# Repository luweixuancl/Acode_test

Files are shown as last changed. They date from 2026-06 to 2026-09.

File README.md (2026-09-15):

# ESP32-C3 GNSS NTP Server

基于 **合宙 CORE ESP32-C3** + **大夏龙雀 DX-GP22** 的一级（Stratum-1）NTP 时间服务器。

## 功能

1. **OLED 状态页**：大字体本地时间；显示当前 WiFi SSID / IP；顶栏角标为星数·时钟态 / RSSI·AP；SYNC/WAIT
2. **OLED 防烧屏**：无操作（默认 10 分钟）自动关断面板，旋钮任意动作唤醒（首个动作仅唤醒不导航）；息屏时长可在 **Screen Off** 菜单或网页 `/cfg` 调档（常亮/1/5/10/30 分钟，NVS `ooff`）
3. **板载双状态 LED**（合宙 CORE 表4-1）：D4（IO12）显示运行/WiFi，D5（IO13）显示 GPS/PPS，高电平有效
4. **旋转编码器菜单**：扫描 WiFi、网页配网、静态 IP、DHCP、时区、异常策略、NTP ACL、温度补偿、息屏、NTP 统计、重启
5. **手动静态 IP**：编码器逐字节编辑；保存时通过 **ARP 探测**检测局域网是否已有相同 IP；当前 IP 与目标一致时提示 `IP unchanged` 并保持在线（不断网重连）
6. **编码器配网**：扫描附近 WiFi → 选择 SSID → 编码器输入密码 → 连接
7. **网页配网**：开启 SoftAP（`NTP-Setup-XXXX` / 密码默认 **`NTP-`+MAC 后 4 位十六进制**，与串口打印的 MAC 对应；**仅 2.4 GHz**）。`/` 始终是只读状态页。打开 `/setup` 或 `/login` 先登录，通过后才进入 `/cfg` 设置；设置页不再出现写口令输入框。`/status` `/metrics` 只读开放。若手机仍显示旧设置页，请强制刷新（缓存了刷固件前的 `/`）。
8. **网页状态**：访问 `http://<设备IP>/` 查看 NTP/GPS/PPS（JS 按 1 Hz 轮询 `/status`，无需整页刷新）；点「设置」进入登录后再到 `/cfg`
9. **FreeRTOS 三任务**：`task-time`(5) 独占 GNSS/NTP，`task-net`(2) 管 WiFi/网页，`task-ui`(1) 管 OLED/编码器/LED；PPS 计数对齐避免 NMEA 迟到导致的整秒跳变
10. **WiFi 事件 + 自动重连**：`GOT_IP`/`DISC`/`SCAN_DONE` 驱动状态机；掉线后无限退避重连（默认开，NVS `arec`；0s/2s/5s/10s/30s 后每 60s 一轮持续搜寻）。**信号消失绝不自动切 SoftAP 配网**——SoftAP 仅在开机无已存 SSID 或菜单 Web Setup 手动触发。本板为 **C3 单核**，不做双核拆分（详见 `docs/wifi_event_fsm.md`）

## 硬件连接

| 模块 | 信号 | ESP32-C3 GPIO |
|---|---|---|
| DX-GP22 | TXD | 1 (UART1 RX) |
| DX-GP22 | RXD | 0 (UART1 TX) |
| DX-GP22 | 1PPS | 4 |
| DX-GP22 | VCC | 3.3V 或 5V（按模块说明） |
| DX-GP22 | GND | GND |
| SH1107/SSD1107 OLED 64×128 | SDA | 8 |
| SH1107/SSD1107 OLED 64×128 | SCL | 10 |
| OLED | VCC/GND | 3.3V / GND |
| KY-040 编码器 | CLK(A) | 2 |
| KY-040 | DT(B) | 3 |
| KY-040 | SW | 5 |
| KY-040 | + / GND | 3.3V / GND |
| 合宙 CORE 板载 D4 | IO12 | 12（高电平有效） |
| 合宙 CORE 板载 D5 | IO13 | 13（高电平有效） |

引脚可在 `include/config.h` 中修改。

**串口分工**：GPIO20/21 是 UART0（板载 CH343 下载/调试，115200）。GNSS 走 UART1（GPIO1 RX / GPIO0 TX，9600）。`pio device monitor` 看的是调试口，不是 GPS。

### 状态 LED

| LED | 现象 | 含义 |
|-----|---|---|
| D4 | 快闪（约 4 Hz） | 配网 AP 模式 |
| D4 | 慢闪（约 1 Hz） | 固件运行中，STA 未连接 |
| D4 | 心跳（约 900 ms 亮 / 100 ms 灭） | WiFi STA 已连接且固件存活 |
| D5 | 灭 | 无 GNSS 信号 |
| D5 | 慢闪 | 已搜星或 ACQ，等待稳定锁定 |
| D5 | 快闪 | Holdover 守时 |
| D5 | 心跳（与 D4 反相短灭） | GPS 锁定（LCK/DEG）且可授时 |
| D4+D5 | 交替狂闪（约 5 Hz） | 某 FreeRTOS 任务超过约 3 s 未响应 |

健康态用「短灭心跳」而非常亮：若灯僵死在常亮/常灭且不再闪断，多半已死机（UI 也停了）。

### DX-GP22 说明

- 默认串口：**9600 8N1**，输出 NMEA 0183
- 定位成功后 **1PPS** 约 1Hz
- 支持 GPS / 北斗 / GLONASS 等多模

## 操作说明

### 主界面

短按编码器进入菜单。

### 菜单项

- **WiFi Scan**：扫描 → 选择热点 → 旋转选字符、短按追加、长按确认连接
- **Web Setup**：打开配网热点，手机连上后访问 `http://192.168.4.1`
- **Set Static IP**：编辑四个字节；长按保存并做 IP 冲突检测（IP 未变则不重连）
- **Use DHCP**：改回自动获取 IP
- **Timezone**：设置 UTC 偏移（默认 +8）
- **Anomaly Mode**：GPS 异常策略 — Refuse（拒授时）/ Holdover 30s / Holdover 300s（写入 NVS）
- **NTP ACL**：Off / AllowList（默认 Off；名单在网页 `/cfg` 编辑）
- **Temp Comp**：片上温度一阶 ppm 补偿（默认 Off；系数在 `/cfg` 改）
- **Screen Off**：息屏时长选档 — Always / 1 / 5 / 10 / 30 分钟（默认 10 分钟，NVS `ooff`）
- **NTP Stats**：served / RATE / DENY / ACL / drop / clients
- **Restart**：重启

主界面显示时钟状态缩写（ACQ/LCK/DEG/HLD/UNS）与 residual；Web `/` 与 `/status` 同步展示。`/cfg` 也可改异常策略、ACL 与息屏时长。

长按编码器：多数界面返回上一级。

### 恢复出厂

冷开机（上电/按复位）时**按住编码器按钮不松**：OLED 显示 `Hold 3s = reset`，持续 3 秒后擦除全部配置（WiFi、口令、静态 IP、时区、异常策略、ACL、温度补偿、息屏时长等）并自动重启；重启后因无已存 SSID 会自动打开 `NTP-Setup-XXXX` 配网热点。3 秒内松开即取消，正常启动，期间串口输出 `[reset]` 日志。

每次**上电周期只复位一次**：复位后的自动重启带 RTC 闩锁，若按钮仍按着不会再次擦写配置；断电重上电后功能恢复可用。

D5（GNSS）：LCK/DEG 心跳；Holdover 快闪；ACQ 慢闪；UNS/无星灭。D4 STA 为心跳。双灯交替狂闪表示任务卡死告警。

## 内网部署（阶段 B）

面向局域网 Stratum-1，**不要**把 UDP/123 直接暴露到公网。

1. **仅 2.4 GHz**：SoftAP 与 STA 都只支持 2.4G；手机若只看 5G 会扫不到 `NTP-Setup-XXXX`。
2. **限流（B1）**：每 IP 约 4 req/s，超限 KoD `RATE`；持续超限 → `DENY` 冷静丢弃；全局约 32 pkt/s 静默丢弃，保护 `task-time`/PPS。
3. **ACL（B3）**：默认 Off。需要更严时在 `/cfg` 开 AllowList，只放行可信客户端 IP（最多 8 条）；空名单=拒绝全部。
4. **管理面**：`/` `/status` `/metrics` 只读开放。`/cfg` `/save` `/scan` 仅接受登录后的会话 Cookie（约 30 分钟）；`/setup` 只显示登录页。口令默认 SoftAP `NTP-`+MAC 后 4 位。设置页不要求再次填写写口令。
5. **升级保配置**：只刷 `firmware.bin` @ `0x10000`，关闭全片擦除，以免清掉 NVS 里的 WiFi/口令/ACL。
6. **观测**：OLED **NTP Stats**、串口约每 60s 一行 `[ntp] …` 摘要、或抓 `http://<ip>/metrics`。

## 编译与烧录

```bash
pio run -t upload
pio device monitor
```

PlatformIO 环境：`esp32-c3-devkitm-1`（Arduino）。

## 客户端测试

```bash
ntpdate -q <设备IP>
# 或
chronyc sources
```

安卓 Termux 与阿里云比对（仅 Python 标准库）：

```bash
pkg install python
curl -L -o ntp_cmp_termux.py \
  https://ghproxy.net/https://raw.githubusercontent.com/luweixuancl/esp32c3-gnss-ntp/main/tools/ntp_cmp_termux.py
python ntp_cmp_termux.py --gps 10.81.127.143
# 冒烟约 1 分钟：
python ntp_cmp_termux.py --quick
```

默认 10 分钟、每 10 秒一轮，同时打设备 UDP/123 与 `ntp.aliyun.com`，并读 `/status` 时钟态。CSV 写在当前目录。手机须与设备同一 2.4 GHz WiFi。

GPS 锁定且 PPS 正常时，应答为 **stratum 1**，Reference ID 为 `GPSS`。未同步时 LI=3 / stratum 16 / RefID `INIT`；Holdover 时仍 **LI=0**（闰秒告警位不复用），靠抬高 root dispersion 与 `/status` 的 `clock.state=HLD` 标明守时。

限流（阶段 B1）：每 IP 默认 4 req/s，超限回 KoD `RATE`；持续超限约 10s 后 KoD `DENY` 并冷静丢弃约 60s；全局约 32 req/s 静默丢弃。`/status` 字段 `served` / `rateLimited` / `denied` / `dropped` / `clients`。OLED 菜单 **NTP Stats**；`http://<ip>/metrics` 文本指标（只读，无口令）。

ACL 白名单（阶段 B3）：默认 **Off**。开启 AllowList 后仅列出的 IPv4（最多 8 条）可取时，未命中静默丢弃；空列表=拒绝全部。OLED **NTP ACL** 切换模式；IP 列表在 `/cfg` 编辑。`/status` 含 `ntpAclMode` / `ntpAcl` / `ntp.aclDenied`。

**不做阶段 C**：NTS、HTTPS、PTP、硬件时间戳、TCXO 等机架级能力对本板（C3 + 无线）成本过高或得不偿失，产品范围止于阶段 A+B 的内网轻量 Stratum-1。

Windows 下若工程路径含非 ASCII 字符导致链接失败，可用 ASCII junction（如 `C:\acode_leds`）再 `pio run`。

## 目录结构

```
include/     配置与头文件
src/         固件源码
docs/        设计方案（如本地时钟与 GPS 检核）
platformio.ini
```

本地时钟 / GPS 交叉检核与异常策略已落地，见 [docs/local_clock_gps_check.md](docs/local_clock_gps_check.md)。

WiFi 事件 FSM、自动重连与 C3 无双核说明见 [docs/wifi_event_fsm.md](docs/wifi_event_fsm.md)。

NTP 比对测试见 [docs/ntp_cmp_test_20260911.md](docs/ntp_cmp_test_20260911.md)（2026-09-11，PC）与 [docs/ntp_cmp_test_20260914.md](docs/ntp_cmp_test_20260914.md)（2026-09-14，Termux；原始 CSV [`docs/cmp_20260914_102829.csv`](docs/cmp_20260914_102829.csv)）。两次结果结合时钟算法的评价见 [docs/clock_eval_two_ntp_cmp.md](docs/clock_eval_two_ntp_cmp.md)。

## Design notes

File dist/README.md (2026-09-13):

# ESP32-C3 firmware (phone flash)

| File | Flash address |
|---|---|
| `firmware_merged_0x0.bin` | `0x0` (all-in-one, **first install**) |
| `esp32c3-firmware-phase-a.zip` | bootloader@0x0, partitions@0x8000, firmware@0x10000 |
| `firmware.bin` (inside zip) | `0x10000` (**updates — preferred**) |

Chip: ESP32-C3. Do not connect phone WiFi to SoftAP while flashing (keeps cellular 5G).

## Keep WiFi credentials across updates

NVS (WiFi SSID/password) lives **outside** the app image. If the flasher **erases whole flash**, credentials are wiped and the device opens SoftAP.

**Recommended for updates:**

1. Flash only `firmware.bin` at **`0x10000`**
2. Turn **OFF** “Erase flash” / “全片擦除” in the Android app
3. Do **not** rewrite bootloader/partitions unless the partition table changed

Use `firmware_merged_0x0.bin` only for blank boards or when you intentionally want a clean NVS.

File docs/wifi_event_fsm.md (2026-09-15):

# WiFi 事件 FSM（ESP32-C3）

本板为 **ESP32-C3 单核 RISC-V**，不能做 APP/PRO 双核拆分。WiFi/lwIP 已在高优先级内部任务中运行；应用仍用三任务（`task-time` / `task-net` / `task-ui`），全部钉在 core 0。

双核拆分仅适用于未来换 **ESP32-S3 / 经典双核 ESP32** 时另立项；C3 路线是 **事件驱动加固 + 自动重连**，不是迁核。

## 原则

- `WiFi.onEvent` 回调只在 WiFi 任务上下文中运行：**只置位 / 打日志**，禁止 `WiFi.begin` / `disconnect` / `scanNetworks` / NVS / 大 `String`。
- 所有 WiFi API 仅在 `task-net` 调用。
- `task-time` 零 WiFi 调用，授时路径不依赖事件。
- 连接仍保留 deadline；事件丢失时靠超时失败（双保险）。

## 事件 → 标志

| Arduino 事件 | 标志 | `task-net` 处理 |
|---|---|---|
| `STA_CONNECTED` | （仅日志） | 仍等 `GOT_IP` |
| `STA_GOT_IP` | `GotIp` | `Connecting → Connected`；停 SoftAP（若需要） |
| `STA_DISCONNECTED` | `Disc` + reason | 连接中 → `Failed`；已连接 → 掉线提示 + 武装自动重连 |
| `SCAN_DONE` | `ScanDone` | `harvestScanResults()` → `lastScan_`；OLED/Web 共用 |

标志在 `WifiManager` 内用 `portMUX` 保护的 `evtFlags_`。

## 连接状态

```
Idle ──beginConnect──► Connecting ──GOT_IP / (WL_CONNECTED+IP)──► Connected
                           │
                           ├──DISC / timeout──► Failed
                           │
Connected ──DISC──► Idle（武装 Reconnect）
```

`pollConnect` 优先消费 `GotIp` / `Disc`，否则回退 `WiFi.status()`+IP，再否则超时。

## 自动重连（NVS `arec`，默认开）

```
Connected --DISC--> armed
  attempt 1: 立即 beginConnect（同一凭据）
  attempt 2..N: 退避 2s / 5s / 10s / 30s，之后稳定 60s 一轮，无限重试
  无放弃阈值：信号消失只周期性搜寻重连，绝不自动开 SoftAP
```

手动 Connect 会 `cancelAutoReconnect()`；Scan 不取消（扫描与 STA 重连可并行）。

常量见 `config.h`：`WIFI_RECONNECT_*`。

## 扫描

- `startScan` 异步 `scanNetworks`；完成以 `SCAN_DONE` 为主，`scanComplete` 为双保险。
- SoftAP 配网是纯 `WIFI_AP`，**没有 STA 接口时 `scanNetworks` 会失败或 0 个 AP**。编码器/网页扫描前若当前是 `WIFI_AP`/`OFF`，先切到 `WIFI_AP_STA`（或 `STA`）再扫。
- 编码器扫网：STA 正在 `Connecting` 时**不** `abortJoin`（会立刻 OLED「失败」，随后才出现 `SCAN_DONE`）。保持 Scanning...，等 `GOT_IP` / heal 后再 `startScan`；仅超时才 `ScanFailed`。
- 结果写入 `lastScan_`；`NetWork::Scanning`（OLED）与 Web `/scan` 都读同一缓存。空列表算成功（OLED 显示 No APs，可再点重试），不再当成 Scan failed。
- ARP probe 期间 `startScan` 仍失败 → Web 返回 `busy`。

## 常见 DISC reason（排障）

| reason | 含义（常见） |
|---|---|
| 2 | `AUTH_EXPIRE` |
| 3 | `AUTH_LEAVE`（本地离开，begin 前 disconnect 常见） |
| 4 | `ASSOC_EXPIRE` |
| 8 | `ASSOC_LEAVE`（本地 leave；**勿当失败**——常与 `disconnect()+begin` 竞态） |
| 15 | `4WAY_HANDSHAKE_TIMEOUT`（密码错误常见） |
| 200+ | 无 AP / 信号丢失等（依 IDF 版本） |

连接中对 reason 2/3/8 保持等待 GOT_IP；`healIfStaUp` 在 FSM 误判 Failed 但射频已拿到 IP 时收复链路，避免下一轮 reconnect 把好连接踢掉。

## SoftAP 配网（仅手动）

- 进入条件只有两处：**开机时无已存 SSID**、**菜单 Web Setup 手动触发**。重连永不放弃，因此信号丢失/密码变化不再自动切 SoftAP（NTP 设备应始终留在原网段重试）。
- 进入后为 **纯 `WIFI_AP`**（不是 `AP_STA`）。
- 原因：`AP_STA` 下残留 STA 扫描常导致 SoftAP **不发 beacon**，手机/电脑扫不到 SSID，但串口仍打印 `Setup AP`。
- SoftAP 仅 **2.4 GHz**（ESP32-C3 无 5 GHz）。手机若只看 5G 列表会漏掉；请在 2.4G WiFi 列表中找 `NTP-Setup-XXXX`。
- SoftAP 密码默认 **`NTP-`+模块 MAC 低 16 位十六进制**（串口打印 `MAC=` / `SoftAP default pass=`）；NVS `appw` 可覆盖。
- 配网成功后再切回 STA（或 `AP_STA` 至停 AP）。

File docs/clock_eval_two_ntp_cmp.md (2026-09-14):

# 时钟算法评价（两次 10 min NTP 比对）

> 依据：[ntp_cmp_test_20260911.md](ntp_cmp_test_20260911.md)、[ntp_cmp_test_20260914.md](ntp_cmp_test_20260914.md)、[local_clock_gps_check.md](local_clock_gps_check.md)  
> 固件：`LocalClock`（PPS 秒尺 + NMEA 交叉检核）及 2026-09-13 起的伺服收紧  
> 日期：2026-09-14

## 总评

在 **ESP32-C3 + 廉价晶振 + Wi‑Fi NTP 测法** 下，当前时钟算法已经达到设计目标，不必再为「把 offset stdev 再压 1 ms」改伺服。

| 维度 | 评价 | 依据 |
|---|---|---|
| 诚实授时 | **优** | 9/14 搜星阶段 stratum 16 / LI=3 / `INIT` / dispersion 65535 s；锁定后立刻 stratum 1 / `GPSS` |
| 锁定后相位 | **优** | 两次锁定段 `residualMs=0`、`ppsFresh=true`；干净 RTT 下 offset stdev **1.3～2.6 ms** |
| 无整秒跳变 | **优** | 相对历史 51.3% 错秒，两次 10 min **0 次** \|GPS−阿里云\| > 400 ms |
| 对公网粗参考 | **通过** | 锁定后 diff 中位 −3～−7 ms；9/14 范围仅 −20～+29 ms |
| 守时 / 拔天线 | **未现场验收** | Holdover 色散、Refuse→UNS 只有代码路径 |
| 对 UTC 的绝对误差 | **本测法不能下结论** | 看到的是客户端钟差 + Wi‑Fi 路径，不是 GNSS 真值 |

**产品表述：** 局域网 Stratum-1 GNSS NTP，客户端体感约 **1～10 ms**。不是电信/PTP/金融同步，也不是「误差 1 ms」的广告语。

---

## 时间线：算法改了什么，两次各测到了什么

| 日期 | 事件 |
|---|---|
| 2026-09-11 | `LocalClock` 初版落地：PPS `esp_timer` 边沿、ppm EMA、LocalUtc、ACQ/LCK/DEG/HLD/UNS |
| 2026-09-11 23:48 | **比对 A**：Windows PC，全程已 LCK，60 轮，设备 `192.168.124.6` |
| 2026-09-13 | Phase A 诚实元数据；PPS 参考时间戳；Holdover 色散按 ppm×age；**8 s 跨度估频**；冷启要 `ppsStable_` 才建锚；Locked 下 \|residual\| &lt; `CLK_LOCKED_SLEW_MS`(5 ms) **不跟 NMEA 重锚**；可选片上温度 trim（默认关） |
| 2026-09-14 10:28 | **比对 B**：Termux 手机，先 ACQ 50 s 再 LCK，60 轮，设备 `10.81.127.143` |

比对 A 是 **伺服初版、已锁定** 的基线。  
比对 B 是 **收紧后的固件**，并且碰巧拍到了 **ACQ→LCK 切换**，把诚实元数据也测到了。

两次客户端、网络、系统钟都不同，**不能**把 −243 ms 和 +24 ms 的绝对 offset 拿来比「谁更准」。能比的是：锁定后稳不稳、会不会整秒跑飞、元数据说不说谎。

---

## 测法边界（评价必须先认）

`offset_ms` 是「服务器相对这台客户端」。里面叠了：

1. 客户端系统钟相对 UTC 的慢/快（9/11 PC ≈ −243 ms，9/14 手机 ≈ +24 ms）
2. 客户端↔设备（或公网）的不对称时延
3. Wi‑Fi 排队/重传（9/14 有 9 次 delay 38–81 ms，offset 跟着跳到 36–61 ms）
4. 设备真实相位（我们真正关心的）

因此：

- **stdev / 相邻步长** 才能谈稳定性；绝对 offset 只描述客户端钟差。
- 9/14 引用稳定性应报 **delay &lt; 20 ms** 的 1.34 ms，不要报含尖峰的 9.16 ms。
- 亚毫秒/微秒级只能靠 PPS 对拍或有线硬件时间戳，这两次都没有。

---

## 分项：优化是否被数据撑住

### 1. 未锁定不授时（Phase A）

设计：`nowUtc()` 只在 LCK/DEG/HLD 返回；NTP 未同步时 LI=3、stratum 16、refid `INIT`、dispersion 拉满。

比对 B 前 5 轮原样出现上述字段，offset 落到 −4×10¹² ms 量级（未同步时间基，不是「慢了 4 百万秒」）。第 6 轮起变为 LI=0 / stratum 1 / `GPSS` / dispersion ≈ 5–6 ms。

**评价：** 这是 9/13 诚实化之后最硬的现场证据。旧病是「模块还没锁也当优质 stratum 1」。现在客户端在搜星阶段不会被骗去校时。

比对 A 开跑时已经 LCK，测不到这一条。

### 2. PPS 走相，NMEA 只做检核

设计：锁定后每个稳定 PPS 把锚点 `utcSec+1`；NMEA 在 **PPS 边界**算 residual；Locked 且 \|r\| &lt; 5 ms 不重锚，避免 NMEA 解析抖动抬高 std。

两次锁定段 **`residualMs` 全程 0**（10 s 采样）。比对 A stdev 2.63 ms、步长中位 1.11 ms；比对 B 干净样本 stdev 1.34 ms、步长中位 0.98 ms。没有秒级台阶，也没有「每秒被 NMEA 拽一下」的锯齿。

**评价：** 5 ms slew 带和 PPS 走相同向。residual 恒 0 说明交叉检核认为相位已贴在整秒上；对外 NTP 起伏被测法底噪盖住（1–3 ms），再抠伺服收益极小。

### 3. 估频（8 s 跨度 + EMA）与冷启

设计：边沿环最近 8 个 1 s 间隔平均再 EMA（α=0.2）；间隔门限 5 ms；冷启要连续好间隔才 `ppsStable_`，不在首个孤边沿建锚。

比对 B 从脚本视角约 50 s ACQ 后进入 LCK（不知上电已多久，只能说「未锁时不会提前 stratum 1」）。比对 A 与 9/11 冒烟：冷启约 90 s → LCK，当时 `freqPpm≈−0.4`（廉价 XO 的正常量级）。

锁定后 root dispersion 钉在 **~6 ms**（quality 地板约 5 ms + 微小 ppm 加成），没有随时间爬升——说明 **没有进入 Holdover/Degraded**，估频也没有把 quality 顶上去。

**评价：** 8 s 跨度足够滤掉单间隔量化噪声；现场没有「锁上又掉、dispersion 乱飘」。温度 trim 默认关，这两次都 **没有** 验证 `tcmp`。

### 4. 相对阿里云

| | 比对 A（伺服初版） | 比对 B（收紧后） |
|--|---|---|
| 配对 | 60（全程 LCK） | 52（LCK；阿里云超时 3） |
| diff 中位 | −3.34 ms | −6.63 ms |
| diff 范围 | −20～**+253** ms | −20～**+29** ms |
| \|diff\| > 400 | 0/60 | 0/52 |

+253 ms 那次 GPS offset 仍贴着 −242 ms 基线，是 **云路径尖峰**，不是设备跳秒。比对 B 云侧更老实，两边粗一致性约 ±20 ms。

验收门槛（设计文档）：`|diff| > 400 ms` 仍为 ~0%，std 不明显恶化。  
**两次都通过。** 收紧后没有把稳定性做坏；B 的「更好」主要是云侧碰巧没尖峰 + 滤了高 RTT，不能单独归功于 8 s 估频。

### 5. 历史病已经闭环

| 阶段 | 现象 |
|---|---|
| 修复前 | 异常率 51.3%，stale 整秒 −1 s → −3～−4 s |
| RTOS + PPS-count 对齐后抽测 | 异常率 0%，配对差中位 ~48 ms |
| LocalClock 初版 + 比对 A | 10 min 无整秒跳；PC 测 stdev 2.6 ms |
| 伺服收紧 + 比对 B | 诚实 INIT→GPSS；干净 stdev 1.3 ms；仍无 400 ms 级异常 |

整秒错标是已消灭的旧 bug。当前算法是在「已经能对上秒」之上，加上 **可见健康度** 和 **宁可拒报**。

---

## 没有被这两次测到的部分

这些优化在代码里，但 CSV **给不出分数**：

- **HoldoverShort/Long**：色散随 ppm×age 增长、超时/质量超 500 ms 转 UNS  
- **Refuse + 拔天线**：应迅速 LI=3，不得假 stratum 1  
- **Degraded（residual 50–100 ms）**：WARN 不重锚、只抬 dispersion  
- **温度补偿**：默认关；片上 TSENS 只是晶振代理，本来就是粗 trim  
- **长 holdover 守时误差**：廉价 XO 按 50 ppm 地板，5 min 理论可漂约 15 ms；未测  
- **PPS 对 UTC 的绝对相位**：Wi‑Fi NTP 看不到 µs

设计文档里「拔天线策略差异」仍待现场；**≥10 min vs 阿里云回归可以勾掉。**

---

## 还要不要继续改算法

| 想法 | 建议 |
|---|---|
| 再加大 ppm 平滑 / 再加 PLL | **不必。** 测法底噪已是 1–3 ms，现场看不出 |
| 默认打开温度补偿 | **先不要。** 未对照；系数 −0.50 ppm/°C 是猜的。要开就单独做一夜对比 |
| 默认 Holdover 代替 Refuse | **产品选择，不是精度问题。** Refuse 更诚实；室内偶发遮挡才值得 Short |
| 宣称亚毫秒 | **不要。** 除非示波器对 PPS 或有线硬件时间戳 |

值得做的现场，按性价比：

1. 锁定后拔天线：Refuse 应变 UNS；HoldoverShort 应 HLD 且 dispersion 上升  
2. 冷启到 LCK 计时（UART/`/status`），确认 8 s 稳 PPS + 3 次 relock 的量级  
3. 需要守时再考虑开 `tcmp` 做对照，而不是先改 EMA

---

## 一句话

两次 10 分钟比对加上 9/13 的伺服收紧，说明这套时钟 **锁得住、不说谎、锁后不抖**，已经匹配硬件与产品定位。剩下的是异常策略的现场验收，不是把毫秒级 NTP 曲线再磨尖。

关于「把 23 ms 当处理延迟扣掉 / 再挪时间戳」的评估见 [ntp_timestamp_eval.md](ntp_timestamp_eval.md)：**23 ms 是客户端钟差；用户态打戳位置已经基本正确。**

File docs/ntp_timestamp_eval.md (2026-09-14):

# NTP 时间戳位置与「固定 23 ms」评估

> 状态：**只评估，不实现**  
> 日期：2026-09-14  
> 依据：`src/ntp_server.cpp` 现网路径；[ntp_cmp_test_20260911.md](ntp_cmp_test_20260911.md)、[ntp_cmp_test_20260914.md](ntp_cmp_test_20260914.md)、[clock_eval_two_ntp_cmp.md](clock_eval_two_ntp_cmp.md)

两条外部建议：

1. **校准固定 offset**：把稳定的约 23 ms 偏差，从 NTP 回复里扣掉「实测处理延迟」，以提升精度。  
2. **优化时间戳位置**：把 Receive / Transmit 打得更贴近「包进 / 包出」。

结论先说：**建议 1 按字面做会损害诚实授时，23 ms 不是处理延迟。建议 2 方向对，但本项目已经做对了用户态该做的大部分，剩余收益在亚毫秒～数毫秒，且被 Wi‑Fi 协议栈封顶。**

---

## 1. 建议 1：扣 23 ms / 扣处理延迟

### 1.1 那 23 ms 是什么

2026-09-14 Termux（锁定、delay &lt; 20 ms）：

| 量 | 中位 |
|----|---|
| GPS `offset` | **+24.0 ms** |
| GPS `delay`（RTT） | **7.5 ms** |
| 阿里云 `offset` | **+31.2 ms** |
| 阿里云 `delay` | **65 ms** |
| GPS − 阿里云 | **−6.6 ms** |

2026-09-11 同一台设备、另一台 Windows PC：GPS `offset` 中位 **−243 ms**，delay 中位 5.3 ms。

同一套固件、两个客户端，绝对 offset 差一个数量级、符号相反。这只能是 **客户端系统钟相对 UTC 的慢/快**，不是设备里有一个固定 23 ms 处理税。

更硬的否证：

- NTP 往返 **delay ≈ 7.5 ms**。处理延迟若真有 23 ms，会直接出现在 RTT 里，不可能「delay 7.5、offset 却稳 23」。  
- 同一只手机看阿里云也是 **+31 ms**。若在 GPS 回复上减 23 ms，手机上 GPS 会变成约 +1 ms，阿里云仍是 +31 ms，**两边差 30 ms**，比现在的 −6.6 ms **更差**。  
- 若把 −23 ms 写进所有回复，9/11 那台已经慢 243 ms 的 PC 会变成约 −266 ms；任何已经用 chrony/ntpd 对准的局域网机器会被 **拉偏 23 ms**。

### 1.2 处理延迟在公式里本来就不进 offset

经典四戳：

```
offset = ((T2 − T1) + (T3 − T4)) / 2
delay  = (T4 − T1) − (T3 − T2)
```

`T3 − T2` 是服务器处理时间。两边打戳只要来自同一把 LocalClock，**处理时间进入 delay，不进入 offset**。再从 T2/T3 上减一遍 `(T3−T2)` 或减一个常数 23 ms，等于人为把服务器钟拨快/拨慢，对「这只未校准的手机」好看，对其它客户端作假。

本项目用户态处理（`parsePacket` 之后：读 48 字节、ACL、速率表、组包、再 `nowUtc`）在 C3 上是 **百微秒～一两毫秒** 量级，不是 23 ms。现网 **没有** 把 `T3−T2` 打进 CSV，所以「实测处理延迟」目前也测过。

### 1.3 什么情况下「减一个数」才合法

只有对着 **比 Wi‑Fi NTP 更真的参考**（示波器对 PPS、有线硬件时间戳、同机房 stratum-1）量出设备钟的 **固定相位误差**，才可以谈校准。手机 vs 设备 vs 阿里云 **不是** 这种参考。

即便将来 PPS 对拍量出例如 +80 µs 的天线/电缆/固件偏置，那是 **相位校准常数**（写进 LocalUtc 或只加在 T2/T3），不是「处理延迟」，也绝不是这次的 23 ms。

### 1.4 建议 1 的裁决

| 做法 | 裁决 |
|---|---|
| 把 +23 ms 当固件常数从回复里减掉 | **否决。** 校准到这只手机，破坏其它客户端和诚实性 |
| 用 `(T3−T2)` 去改 T2 或 T3 | **否决。** 公式已处理；再减是双重计数 |
| 日志里打出 `T3−T2`，确认用户态处理 &lt; 2 ms | **可做，观测项**，不改授时 |
| PPS 对拍后再谈 µs 级相位常数 | **以后的事**，与本次 23 ms 无关 |

---

## 2. 建议 2：优化时间戳位置

### 2.1 现在打在哪

`NtpServer::handlePacket` / `sendNormal`（`task-time`，1 ms 轮询 + PPS notify）：

```
parsePacket()          ← 包已在 lwIP 套接字里（Wi‑Fi RX 栈延迟已经发生）
nowUtc() → T2          ← Receive Timestamp（读 payload 之前，用户态尽可能早）
read 48B
ACL / 限速
组包（LI/stratum/dispersion/ref/org）
把 T2 写入 Receive
nowUtc() → T3          ← Transmit Timestamp
beginPacket + write + endPacket   ← 之后还有 lwIP / Wi‑Fi TX 栈
```

对照「理想位置」：

| 戳 | 理想 | 现状 | 偏差方向 |
|----|---|---|---|
| T2 Receive | 包到达网卡 / 驱动 RX | `parsePacket` 之后立刻 `nowUtc` | **偏晚**（Wi‑Fi RX + 任务最多约 1 ms 调度） |
| T3 Transmit | 包离开网卡 / 已交给驱动 TX | 组包后、`beginPacket` 前 `nowUtc` | **偏早**（TX 栈还没走） |

用户态顺序 **已经基本正确**：T2 在 `read`/ACL/限速之前；T3 在组包之后、发送之前；T2≠T3。这比「收发共用一个戳」或「读完、限速完才打 T2」要好。

### 2.2 晚 T2 / 早 T3 对客户端的影响

- T2 偏晚 `d_rx` → offset 大约 **+ d_rx / 2**（设备显得快）  
- T3 偏早 `d_tx` → offset 大约 **− d_tx / 2**（设备显得慢）  
- 二者接近时大致对消；Wi‑Fi 上往往 RX 排队更肥，可能剩 **+0.5～数 ms** 的系统偏置  

这解释得了「干净样本里 1～3 ms 的测法起伏」，**解释不了稳定的 +24 ms**（且阿里云同样 +31 ms）。

`precision` 在 PPS 就绪时已是 −10（≈1 ms），和这条残差同一量级，元数据没有吹牛。

### 2.3 还能往哪挪（按侵入性）

| 档 | 做法 | 预期收益 | 代价 / 风险 | 建议 |
|----|---|---|---|---|
| A | T3 挪到 `write` 之后、`endPacket` 之前 | 百微秒 | 几行，几乎无风险 | **若动手，只做这一档** |
| B | `parsePacket` 成功后第一件事只读 `esp_timer`，组包时再换成 UTC | 与现在几乎相同（`nowUtc` 已是 `esp_timer` 外推） | 无实质收益 | 不做 |
| C | 缩短 `parsePacket` 到处理的调度：PPS/NMEA 后再 `ntp.loop` 的顺序已是先 GPS 后 NTP；C3 单核无法并行 | 偶发 1 ms 级 | 已是 prio 5 + 1 ms 票 | 维持现状 |
| D | lwIP / `WIFI_EVENT` / 驱动 RX 回调里打 T2 | 或许可再挤 0.5～2 ms | 要绕开 Arduino `WiFiUDP`；ISR/回调里不能重活；和现架构「任务内打戳」冲突；难测 | **不做**（C3 + Arduino 不值） |
| E | 硬件时间戳 / PTP | µs | C3 Wi‑Fi 无可用 PTP；已划为非目标 | **不做** |

A 的收益远小于测法底噪（手机/PC Wi‑Fi NTP 1–3 ms），**单独做看不出 CSV 变好**。它的价值只是「顺序更教科书」，不是精度跃迁。

---

## 3. 和项目约束的对齐

- **诚实 NTP（Phase A）**：未锁定 `INIT`；锁定后 T2/T3 必须是 LocalUtc，不能为了某只手机减常数。  
- **C3 单核**：时间戳再往驱动里塞，会和 PPS ISR、UART1 抢同一核，收益不确定。  
- **产品定位**：局域网 1～10 ms，不是机架 µs 钟。建议 1 若落地，广告上会变成「对着我的手机校过」，和文档承诺相反。  
- **测法**：要证明「打戳位置」有效，必须 **同一客户端、改前/改后、看 delay 分布和 T3−T2**，不能看绝对 offset 是否靠近 0。

---

## 4. 方案（仍不实现，除非以后单独立项）

### 不做

1. 任何形式的「−23 ms」或「按某次 Termux 中位数校准」。  
2. 用 `(T3−T2)` 去改对外时间戳。  
3. 驱动/lwIP 级 RX 时间戳、硬件 TS。

### 若以后要动，按这个顺序

1. **观测（推荐，低风险）**  
   - 在 `sendNormal` 里用已有的 T2/T3 算 `procUs`，UART 或 `/status` 打 p50/p95（不要写进 NTP 包）。  
   - 预期：锁定时空载 p50 &lt; 1 ms，p95 &lt; 3 ms。若真出现经常 &gt; 5 ms，再查限速表或 GPS `loop` 是否挡住 `ntp.loop`。  
   - 复测仍用 `tools/ntp_cmp_termux.py`，**只看 delay 与步长，不看 offset 是否靠近 0**。

2. **打戳微移（可选，档 A）**  
   - T3 紧贴 `endPacket` 之前。  
   - 不改 T2 语义（保持 `parsePacket` 后第一时间）。  
   - 验收：`procUs` 略增（把组包算进处理，这是对的）；客户端 offset stdev **不应明显变**；`|GPS−阿里云|` 中位仍 &lt; 50 ms。

3. **相位校准（仅当有真参考）**  
   - PPS 对拍或有线参考之后，才能谈 `phaseOffsetUs` 写入 LocalClock。  
   - 与「处理延迟」分字段，禁止和 23 ms 混用。

### 验收红线

- 禁止让「这只手机 offset≈0」成为通过条件。  
- 禁止改变未锁定时的 LI=3 / stratum 16 / `INIT`。  
- 禁止为打戳把重活放进 ISR。

---

## 5. 一句话

**23 ms 是手机钟，不是设备税；扣它会让 NTP 对其他客户端说谎。时间戳位置值得保持「早 T2、晚 T3」，但现在已经在用户态该停的地方，再往下是 Wi‑Fi 栈，不是再减一个常数能解决的。**

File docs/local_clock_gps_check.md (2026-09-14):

# PPS 校准本地时钟与 GPS 交叉检核

> 状态：已实现（含审核修复：Holdover 在 PPS 丢失时生效、WARN→Degraded 不重锚、策略缓存、PPS 原子拷贝、NTP LI/RefID 诚实化）  
> 日期：2026-09-11  
> 相关分支：`cursor/esp32c3-status-leds-5075`  
> 前置：FreeRTOS 三任务 + PPS-count 对齐（已落地）

## 1. 目标与非目标

### 目标

- 用 PPS 把 ESP32-C3 本地单调时钟校准成「准秒尺」
- 用校准后的本地 UTC 与 NMEA 交叉比对
- 偏差超阈 → 抬高 root dispersion；严重时 LI=3 / stratum 16
- **GPS 异常后策略由用户配置**（OLED 菜单 + Web 设置页），写入 NVS
- 逻辑只在 `task-time` 运行，不阻塞 net/ui

### 非目标（本阶段）

- 不上外部 TCXO / 完整 chrony 风格 PLL
- 不把系统 `gettimeofday` 当作对外授时源
- SoftAP 密码默认 `NTP-`+MAC 后 4 位（NVS `appw` 可覆盖）；同步时 RefID `GPSS`，未同步时 RefID `INIT`

## 2. 已落地能力（相对初版缺口）

当前实现已具备：

- `LocalClock`：PPS `esp_timer` 边沿环、ppm EMA、LocalUtc 外推
- NMEA 在 **PPS 边界** residual 交叉检核（RELOCK / WARN / FAIL）
- 状态机 ACQ / LCK / DEG / HLD / UNS；NTP 仅 LCK/DEG/HLD 授时
- PPS 或 NMEA 丢失时：Refuse → Unsynced；Holdover* → 本地守时至超时
- AnomalyPolicy + `holdoverSec` 经 OLED/Web 写入 NVS（`apol`/`ahold`）

## 3. 双时间基模型

```mermaid
flowchart TB
  ppsIsr[PPS_ISR] -->|edgeUs esp_timer| localScale
  localScale[LocalScale_ppm] --> localUtc[LocalUtc]
  nmea[NMEA_commit] --> residual[Residual_ms]
  localUtc --> residual
  residual -->|ok| discipline[Update_anchor]
  residual -->|warn_fail| ntpMeta[LI_dispersion_policy]
  localUtc --> nowUtcOut[nowUtc]
  policy[AnomalyPolicy_NVS] --> ntpMeta
```

### 3.1 LocalScale（本地秒尺）

| 项 | 设计 |
|----|---|
| 时间源 | ISR 记录 `esp_timer_get_time()`（µs，64-bit）。`millis()` 分辨率不足以估斜率 |
| 缓冲 | 最近 8～16 个 PPS 边沿 |
| 估计 | 边沿环最近 `CLK_PPM_SPAN_SEC`（默认 8）个 1s 间隔的平均误差 → `freqPpm`（再 EMA） |
| 相位锚 | 信任后的 `(utcSec0, edgeUs0)` |
| 异常 | \|间隔 − 1s\| > 5 ms 连续 3 次 → `PpsUnstable` |

ISR 保持极短：写边沿时间戳 + `ppsCount++` + `vTaskNotifyGiveFromISR`；滤波在 time 任务内完成。

### 3.2 LocalUtc（外推）

```
dt = (nowUs - edgeUs0) * (1 - ppm * 1e-6)
utc = utcSec0 + dt
```

**授时输出策略**

- **Locked / Degraded / Holdover**：每个 PPS 边沿将锚点 `utcSec` +1（相位跟 PPS 走）
- **NMEA**：交叉检核；Acquiring 时允许重锚；Locked 下仅当 \|residual\| ≥ `CLK_LOCKED_SLEW_MS` 才轻量纠相，避免秒级 NMEA 抖动抬高 std
- NMEA 提交时用 `ppsCount` lag 对齐「最后边沿对应的整秒标签」，避免 -1 s 级假 residual
- 冷启锚定要求 `ppsStable_`（连续好间隔），不在首个孤边沿上建锚
- Holdover 年龄用 `esp_timer`（与秒尺同源），不用 `millis()`
- **可选温度补偿**（NVS `tcmp` 默认关）：片上 TSENS 约 1 Hz；相对最近一次 PPS 估频时的温度做 `Δppm = k·ΔT`（默认 k=-0.50 ppm/°C，钳位 ±20 ppm）。关时行为与原先完全相同。

## 4. 交叉检核

在 NMEA **新秒**提交时（沿用 `epoch != lastCommittedSecond_`）：

**比对必须在 PPS 整秒边界**，不能用「解析完成时刻」，否则会把 100～800 ms 解析延迟算进 residual。

```
residualMs = UTC(NMEA 秒 T 的边界) - LocalUtc(at PPS_edge_T)
```

### 阈值（`include/config.h`）

| 宏 | 建议默认 | 含义 |
|----|---|---|
| `CLK_RESIDUAL_WARN_MS` | 50 | 进入 Degraded；抬高 dispersion / UI warn |
| `CLK_RESIDUAL_FAIL_MS` | 100 | 检核失败，按 AnomalyPolicy 处理 |
| `CLK_RESIDUAL_RELOCK_MS` | 30 | 恢复 Locked 的 residual 上限 |
| `CLK_RELOCK_COUNT` | 3 | 连续通过次数 |
| `CLK_PPS_INTERVAL_MAX_ERR_US` | 5000 | PPS 间隔异常门限 |
| `CLK_PPS_UNSTABLE_COUNT` | 3 | 连续间隔异常次数 |
| `CLK_PPM_SPAN_SEC` | 8 | 估频平均间隔秒数（边沿环） |
| `CLK_TEMP_COMP_DEFAULT` | 0 | 温度补偿默认关 |
| `CLK_TEMP_COEFF_CENTI` | -50 | 默认 -0.50 ppm/°C |
| `CLK_HOLDOVER_SHORT_SEC` | 30 | 短守时默认秒数 |
| `CLK_HOLDOVER_LONG_SEC` | 300 | 长守时默认秒数 |
| `CLK_HOLDOVER_PPM_FLOOR` | 50 | 守时色散晶振误差下限 (ppm) |
| `CLK_HOLDOVER_PHI_PPM` | 15 | NTP PHI 下限 (ppm)，色散增速不低于此值 |
| `CLK_HOLDOVER_ENTRY_MS` | 100 | 进入守时额外不确定性 (ms) |
| `CLK_HOLDOVER_MAX_QUALITY_MS` | 500 | 守时质量超此值提前 Unsynced |

## 5. 状态机

```mermaid
stateDiagram-v2
  [*] --> Acquiring
  Acquiring --> Locked: PPS稳且NMEA一致
  Locked --> Degraded: residual达WARN
  Locked --> Unsynced: residual达FAIL且Refuse
  Locked --> Holdover: residual达FAIL或NMEA停且Holdover策略
  Degraded --> Locked: 连续恢复
  Degraded --> Unsynced: FAIL且Refuse
  Degraded --> Holdover: FAIL且Holdover策略
  Holdover --> Locked: NMEA回来且一致
  Holdover --> Unsynced: 超时或质量超阈或PPS不稳
  Unsynced --> Acquiring: 数据流恢复
```

| 状态 | NTP 行为 | OLED / Web |
|---|---|---|
| Acquiring | LI=3，stratum 16，RefID `INIT` | D5 闪；`timeValid=false` |
| Locked | LI=0，stratum 1，dispersion 小，RefID `GPSS`；Reference=末次 PPS 整秒 | D5 心跳 |
| Degraded | LI=0，stratum 1，dispersion ≥ \|residual\|，RefID `GPSS` | 网页 warn |
| Holdover | LI=0，stratum 1，dispersion 随时间增大（entry+ppm×age），RefID `GPSS`；质量超阈或超时 → Unsynced | 标明 holdover（`clock.state=HLD`） |
| Unsynced | LI=3，stratum 16，RefID `INIT` | D5 闪/灭 |

> **LI 语义**：RFC 的 LI 仅表示闰秒告警，**不用 LI=1 表示 Holdover**。守时状态靠 dispersion 与管理面（OLED/`/status`）表达。

**WARN（三种策略相同）**：仍可 stratum 1，但 dispersion 必须反映 residual。

## 6. 用户可配置：异常后策略

不做编译期二选一，作为 **运行时可配选项**，OLED 与 Web 均可修改，持久化到 NVS。

### 6.1 数据模型（`AppSettings`）

```cpp
enum class AnomalyPolicy : uint8_t {
  Refuse = 0,        // 立即拒绝授时
  HoldoverShort = 1, // 短时守时
  HoldoverLong = 2,  // 长时守时
};

AnomalyPolicy anomalyPolicy = AnomalyPolicy::Refuse;  // 默认最保守
uint16_t holdoverSec = 30;  // Refuse 时忽略；Short/Long 可覆盖预设
```

### 6.2 NVS（namespace `ntp-srv`）

| Key | 类型 | 默认 | 说明 |
|-----|---|---|---|
| `apol` | uint8 | `0` | `AnomalyPolicy` |
| `ahold` | uint16 | `30` | 守时秒数；选 Long 时 UI 可默认写入 `300` |

`task-time` **只读快照**（经 `settings` mutex 拷贝），避免持锁做授时。

### 6.3 策略语义

| 策略 | FAIL / NMEA 停滞且 PPS 仍稳时 |
|---|---|
| **Refuse** | 立即 → Unsynced，不守时 |
| **HoldoverShort** | → Holdover，默认 30 s 后 Unsynced（NMEA 停滞 **或** PPS 丢失均可进入，靠 LocalUtc 外推） |
| **HoldoverLong** | → Holdover，默认 300 s 后 Unsynced |

切换策略时：

- **不重启**即可生效（下一轮 NMEA 提交或状态机 tick 读新快照）
- 若当前已在 Holdover：按**新策略**重算剩余时间；改成 Refuse → 立即退出 Holdover 进入 Unsynced
- 不强制重置 LocalUtc 锚点（除非进入 Unsynced/Acquiring 需要重新捕获）

### 6.4 OLED 菜单（GUI）

在现有菜单（`Timezone` / `Restart` 旁）增加：

**`Anomaly Mode`**

- 旋转切换：`Refuse` / `Hold 30s` / `Hold 5m`（短文案适配 128 宽）
- 短按：写入 NVS + `showMessage("Saved")`
- 长按：返回

首页可选缩写：`A:REF` / `A:H30` / `A:H5m`。

（进阶可选：Holdover 下再进一页调 `holdoverSec` 10～600；首版用三档预设即可。）

### 6.5 Web 设置页

扩展 `/setup`（不仅 WiFi）：

- 下拉框「GPS 异常策略」：Refuse / Holdover 30s / Holdover 5min
- `POST /save` JSON 增加 `anomalyPolicy`（及可选 `holdoverSec`）
- 状态页「WiFi 配网」链可改为「设置」，STA 下也能改策略
- `/status` JSON 增加只读字段：`anomalyPolicy`、`holdoverSec`；LocalClock 落地后另加 `clock.state`、`residualMs`、`freqPpm`

`handleSave` 持 `settingsLock` 更新 `gSettings` + `gStore.save`。

## 7. 模块挂接

| 模块 | 变更 |
|---|---|
| `settings` | `AnomalyPolicy`、`holdoverSec`；load/save `apol`/`ahold` |
| `gps_service` 或新 `local_clock` | 边沿环、ppm、LocalUtc、residual、状态机；读策略快照 |
| `ntp_server` | 按状态输出 LI/stratum/dispersion |
| `display_ui` | 菜单项 + 首页缩写 + 可选 residual |
| `web_portal` | `/setup` 表单、`/save`、`/status` 字段 |
| `config.h` | 第 4 节阈值与 holdover 默认秒数 |
| `status_leds` | Unsynced/Acquiring 与现有 D5 语义对齐；Holdover 可用慢闪区分（实现时定） |

## 8. 实现顺序

1. ~~**配置面**：settings + NVS + OLED「Anomaly Mode」+ Web 下拉~~ ✅
2. ~~**LocalScale**：`esp_timer` 边沿环 + ppm EMA + 间隔健康~~ ✅
3. ~~**LocalUtc**：锚定；Locked 时 `nowUtc` 切本地外推~~ ✅
4. ~~**交叉检核状态机** + NTP/UI 字段~~ ✅
5. ~~**按 `anomalyPolicy` 接 Holdover 分支~~ ✅
6. **验收**：烧录 + 短监测回归已通过冒烟（LCK / LI=0 / stratum 1）；**≥10 min vs 阿里云已通过两次**（2026-09-11 / 2026-09-14）。拔天线 Holdover/Refuse 差异仍待现场补测。综合评价见 [clock_eval_two_ntp_cmp.md](clock_eval_two_ntp_cmp.md)。

冒烟（2026-09-11）：冷启约 90 s → `clk=LCK`、`residualMs=0`、`freqPpm≈-0.4`；8 轮 vs aliyun 中位差 ≈ +46 ms，无整秒跳变。
## 9. 验收标准

| 场景 | 通过条件 |
|---|---|
| 正常锁定 | residual 中位 &lt; 20 ms；LI=0 stratum 1 |
| Refuse + 拔天线 | 迅速 Unsynced（LI=3），无假 stratum 1 守时 |
| HoldoverShort + 短暂遮挡 | 进入 Holdover，dispersion 上升，超时后 Unsynced |
| HoldoverLong | 守时窗口明显长于 Short |
| OLED/Web 改策略 | NVS 持久化，刷新/重启后保持；不需重编译 |
| 回归 ≥10 min vs aliyun | \|diff\| &gt; 400 ms 仍为 ~0%；std 不明显恶化。**已通过**（9/11：0/60；9/14 锁定后：0/52） |
| 实时性 | ISR 仍极短；time 任务 1 ms 级轮询不变 |

## 10. 风险与注意

- 斜率与 residual 必须用 **µs 级** `esp_timer`，不能依赖 `millis`
- residual 必须在 **PPS 边界**比较，否则假告警
- 冷启动 Acquiring：宁可不授时，勿用未校准 LocalUtc
- 边沿环跨 ISR / 任务：沿用 `portMUX`
- 默认 **Refuse**：固件升级后行为最保守，符合「诚实 NTP」

## 11. 文档与代码同步（实现时）

- 更新 `AGENTS.md` Architecture：LocalClock 状态机、AnomalyPolicy、residual 阈值
- 更新 `README.md`：菜单项、Web 设置、LED/状态页对 Degraded/Holdover 的含义
- 本文件在实现里程碑处把文首「待实现」改为对应状态并补提交哈希

## 12. 与历史测试的关系

- 基线（修复前）：异常率 51.3%，整秒 stale −1 s → −3～−4 s（见 `ntp_test_report.md`）
- RTOS + PPS-count 对齐后抽测：异常率 0%，配对差中位 ~48 ms
- 本方案在「已消除整秒跳变」之上，增加 **GPS 健康可见性与可配置失效策略**，避免模块错秒时仍被客户端当作优质 stratum 1
- 2026-09-13 伺服收紧（8 s 估频、Locked 5 ms 不跟 NMEA 重锚、诚实 INIT）后，2026-09-14 Termux 10 min 干净样本 stdev 1.34 ms，并拍到 ACQ→LCK；评价见 [clock_eval_two_ntp_cmp.md](clock_eval_two_ntp_cmp.md)

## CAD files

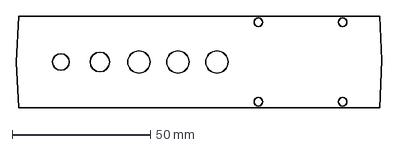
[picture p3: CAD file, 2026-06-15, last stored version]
GNSSTimerServer_Dual/GNSSTimeServer/resources/painel_frontal-v4.DXF
132.0 x 33.0 mm

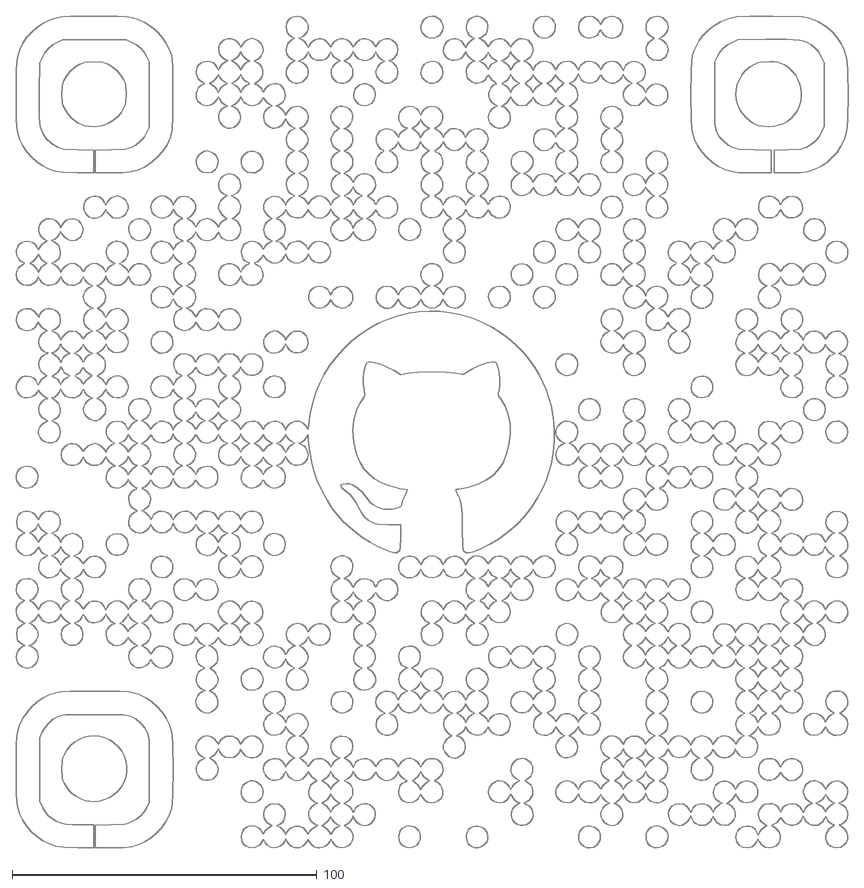
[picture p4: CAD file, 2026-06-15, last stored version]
GNSSTimeServer/resources/3DPrintableCase/qr-code6.dxf
272.8 x 272.8

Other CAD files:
GNSSTimerServer_Dual/GNSSTimeServer/resources/3DPrintableCase/Case_Ver2-Bottom.stl
GNSSTimeServer/resources/3DPrintableCase/Case_Ver2-Bottom.stl
GNSSTimeServer/resources/painel_frontal_dimensoes.SLDPRT
PPS-ntp-server-master/PPS-ntp-server-master/3d-objects/topv4b.stl
GNSSTimerServer_Dual/GNSSTimeServer/resources/3DPrintableCase/Case_Ver2-FPanel.stl
GNSSTimerServer_Dual/GNSSTimeServer/resources/painel_frontal_dimensoes.SLDPRT
GNSSTimeServer/resources/3DPrintableCase/Case_Ver2-Top_Github-QR_Code.stl
PPS-ntp-server-master/PPS-ntp-server-master/3d-objects/bottom_v4.stl
GNSSTimerServer_Dual/GNSSTimeServer/resources/3DPrintableCase/Case_Ver2-BPanel.stl
GNSSTimerServer_Dual/GNSSTimeServer/resources/painel_frontal-v4-perfurado.SLDPRT
GNSSTimeServer/resources/3DPrintableCase/Case_Ver2-FPanel.stl
GNSSTimeServer/resources/painel_frontal-v4-perfurado.SLDPRT
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

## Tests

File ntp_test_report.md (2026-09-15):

# NTP 服务器测试报告

> 测试对象：`10.81.127.143`（GPS 时间源 NTP 服务器）
> 测试日期：2026-09-10
> 测试环境：安卓设备（`/mnt/sdcard`），Python3 内联脚本测量（无 ntpdate/chrony 工具）
> 状态：已完成方案 E 长时监测，待服务器管理员修复后复测

---

## 0. 结论摘要（TL;DR）

| 问题 | 答案 |
|---|---|
| 10.81.127.143 能用作校时源吗？ | **❌ 不能。** 30 分钟监测异常率 **51.3%**（27 段 episode），时间落后幅度从 ~1s **恶化至 3~4s**，疑似 GPS 失锁+守时漂移（见 2.4/2.5） |
| 本机时间真实偏差？ | 比标准时间**慢约 596 ms**（GPS/aliyun 双源交叉验证，正常时两源一致性好于 25 ms） |
| 推荐校时方案？ | 安卓设备改用 `ntp.aliyun.com`（实测精度 std ~5ms，极稳）；`time.android.com` 国内被墙不可用（见 2.3） |
| 服务器还能救吗？ | 大概率可以：正常时与 aliyun 一致性 ~20ms，属授时质量良好的服务器。需管理员按 2.5 节清单排查（GPS 锁星、chrony/ntpd、holdover、PPS），修复后用 `monitor_ntp.py` 复测，异常率 <2% 即可恢复使用 |

**文档结构**：1 服务器信息 · 2 测试记录（2.1 连通性 → 2.4 配对发现异常 → 2.5 长时监测实锤） · 3 Android 同步机制 · 4 待办 · 5 更新日志

---

## 1. 服务器基本信息

| 项目 | 结果 |
|---|---|
| IP | 10.81.127.143 |
| NTP 版本 | v4（server 模式） |
| Stratum | 1（一级时钟源） |
| 时间源 | GPS（Reference ID: `GPSS`） |
| 可用性 | ❌ **不可靠：长时监测异常率 51.3%，且持续恶化（见 2.5），暂不可作为校时源** |

---

## 2. 测试记录

### 2.1 单次连通性测试

- 响应正常，网络往返 21.7 ms
- 本机时间比服务器慢约 0.6 秒（单次采样）

### 2.2 30 次采样统计（间隔 1s，标准 NTP 偏移公式）

| 指标 | 数值 |
|---|---|
| 成功率 | 30/30 |
| 偏移中位数 | **-604 ms** |
| 偏移标准差 | 485 ms（受网络抖动影响偏大） |
| 偏移范围 | -1842 ~ -504 ms |
| 延迟中位数 | 27 ms |
| 延迟最大值 | 472 ms |

**关键发现：偏移呈三个簇**
- 主簇：-500 ~ -610 ms（20 次，正常网络时）
- 次簇：-1500 ~ -1600 ms（9 次）
- 离群：-1842 ms（1 次）

偏移跳变与网络延迟尖峰（27ms → 472ms）强相关，最初归因于非对称网络抖动（Wi-Fi）。依据 NTP 理论，最小延迟样本偏移最准确，即本机比 GPS 服务器**慢约 600 ms**。

> **修正（2026-09-10，依据 2.4 配对分析）**：延迟尖峰最多造成 ±472 ms 误差，无法解释 -1000 ms 级跳变。真实原因是 **GPS 服务器偶发返回整体慢 ~1s 的时间戳**（详见 2.4 第 2 点），属服务器侧问题。

### 2.3 GPS 服务器 vs 公共 NTP 对比（各 20 次交替采样）

| NTP 服务器 | 可达性 | Stratum | 偏移 | 延迟 |
|---|---|---|---|---|
| GPS 服务器 10.81.127.143 | ✅ | 1 | -547 ms | 128 ms |
| time.android.com（安卓自带） | ❌ 全部超时（被墙） | - | - | - |
| ntp.aliyun.com | ✅ | 2 | -605 ms | 36 ms |
| ntp.tencent.com | ✅ | 2 | -603 ms | 47 ms |
| cn.pool.ntp.org | ✅ | 2 | -609 ms | 55 ms |
| time.windows.com | ❌ 超时 | - | - | - |

**结论：**
1. 安卓自带的 `time.android.com`（谷歌）在此网络完全不可达（UDP 123 被墙），这是国内手机"自动确定时间"失效的根源。国内 ROM 通常改用厂商 NTP 或运营商 NITZ（基站时间）。
2. 可达服务器一致性好：GPS（stratum 1）与阿里/腾讯/pool（stratum 2）测得偏移仅差 ~60 ms，都确认本机慢 0.55~0.61 秒。两者授时质量对手机场景等价。
3. ~~精度瓶颈在本机测量链路（Wi-Fi 抖动 + 系统调度延迟），不在服务器。~~ **已被 2.4 修正：跳变主因是 GPS 服务器侧时间戳异常，本机链路对 aliyun 采样全程稳定（std < 6 ms）。**

### 2.4 方案 C：GPS vs ntp.aliyun.com 严格精度对比（30 轮交替采样，间隔 1s）

方法要点：两服务器逐轮交替采样，可用**逐轮配对差值**完全消除本机时钟漂移和整体网络状况变化的影响；最小延迟 20% 样本过滤（NTP 标准做法：最小延迟样本最准确）。

| 指标 | GPS 服务器 10.81.127.143 | ntp.aliyun.com |
|---|---|---|
| 成功率 | 30/30 | 30/30 |
| 偏移中位数 | -594.77 ms | -596.58 ms |
| 偏移标准差 | **434.48 ms** ⚠️ | **5.94 ms** ✅ |
| 偏移范围 | -1608 ~ -522 ms | -608 ~ -586 ms |
| 延迟中位数 / 最大 | 94.8 / 191.6 ms | 60.4 / 76.1 ms |
| 最小延迟 20% 样本标准差 | 516.62 ms | **3.91 ms** ✅ |

**逐轮配对差值（GPS − 阿里）：中位数 +1.44 ms，均值 -206.63 ms，标准差 435.37 ms，范围 [-1011.4, +84.1] ms**

**关键分析：**
1. **正常时两源几乎完全一致**：配对差中位数仅 +1.44 ms，偏移中位数差 1.8 ms → 本机真实偏差约 **-595.7 ms**。
2. **GPS 服务器存在 ~1 秒"时间回退"异常**：GPS 读数偶发跳到约 -1600 ms（恰好慢 ~1000 ms），而此时往返延迟仍正常（≤192 ms）。网络延迟最多造成 ±192 ms 误差，无法解释 -1000 ms 跳变；唯一自洽的解释是**服务器偶尔返回整体慢约 1 秒的时间戳（t2/t3 同时变旧时往返延迟不变），即其 GPS 授时/守时机制偶发失步**。aliyun 全程稳定（std < 6 ms）反证本机链路正常。
3. **精度结论**：ntp.aliyun.com 精度 ≈ 4~6 ms（极稳）；GPS 服务器中位精度与阿里同级（差 ~1.4 ms），但有约 20~30% 概率返回偏差 ~1s 的陈旧时间。**作为校时源暂不如公共 NTP 可靠，建议排查该服务器 GPS 授时模块/守时时钟。**

### 2.5 方案 E：30 分钟长时监测（2026-09-10 15:44:02 ~ 16:14 UTC+8，间隔 5s，GPS vs ntp.aliyun.com 交替）

原始数据：`ntp_monitor_20260910_154402.csv`（275 轮 / 550 样本，含完整 t1~t4 原始时间戳）；分析输出：`analysis_result.md`；工具：`monitor_ntp.py` / `analyze_ntp.py`。

**总体结果：**

| 指标 | GPS 服务器 | ntp.aliyun.com（参照） |
|---|---|---|
| 成功率 | 275/275 (100%) | 269/275 (97.8%) |
| 偏移中位数 | **-1531 ms** | -597 ms |
| 偏移标准差 | 1439 ms | 5.77 ms |
| 延迟中位数/最大 | 66.8 / 317 ms | 53.0 / 242 ms |

**配对差分析（GPS − aliyun，消除本机因素）：**
- 正常样本（\|diff\|≤400ms）：131 轮（48.7%），中位数 +22.5 ms，标准差 20.7 ms ← **健康基线：与 aliyun 一致性良好**
- 异常样本：138 轮（**51.3%**），全部为 stale（服务端时间整体变旧）
- 异常 episode：27 段

**异常演化过程（关键发现——服务器在恶化）：**

| 时段 (UTC) | 特征 |
|---|---|
| 15:44 ~ 16:01 | 异常呈周期性：每 ~30~45s 出现一段 1~3 轮（5~10s）的 stale，幅度稳定在 **-980 ms（约慢 1 秒）**，类似"落后 1 秒又追上"的循环 |
| 16:00 ~ 16:01 | episode 变长至 15 轮（~72s），幅度仍 ~-1s |
| 16:01 ~ 16:07 | （过渡） |
| 16:07:50 ~ 16:13:34 | **连续 68 轮（~344 秒）异常，幅度 -2.9 ~ -4.0 秒** ← 服务器时间额外落后了 2~3 秒 |
| 16:13:47 ~ 16:14 | 回落到 -2.9 ~ -3.0 秒 |

**证据链（排除法）：**
1. 异常期间网络往返正常（GPS 延迟中位 67ms、最大 317ms），延迟最多解释 ±0.3s 误差，无法解释 1~4s 偏差 → **排除网络**
2. 参照源 aliyun 全程稳定（std 5.77ms），本机采样机制无异常 → **排除本机测量问题**
3. 异常幅度呈整秒级（-0.98s → -3~-4s），t2/t3 同时变旧（延迟不变）→ **服务器侧时间戳整体变旧**
4. 30 分钟内幅度从 ~1s 恶化到 ~4s → **服务器守时在持续失步，疑似 GPS 失锁后振荡器自由漂移**

**结论：❌ 10.81.127.143 当前不可作为校时源。** 正常时授时质量良好（与 aliyun 差 ~20ms），但过半时间返回落后 1~4 秒的时间，且偏差在扩大。需服务器管理员立即排查。

**给服务器管理员的排查建议（按优先级）：**
1. **GPS 接收机锁星状态**：锁星数、信噪比、天线/馈线/防雷器是否受损（失步最常见原因）；异常循环周期（~30-45s）疑似与 GPS 接收机输出更新周期相关
2. **授时守护进程状态**：`chronyc tracking`（关注 leap status、Last offset、RMS offset、源状态）或 `ntpq -c rv`（关注 leap、sync 状态）；检查 `makestep`/`tinker panic` 配置是否允许了异常步进
3. **守时振荡器（holdover）**：GPS 失锁后晶振自由漂移与"落后逐秒扩大"的特征吻合；检查振荡器锁定/健康状态
4. **PPS 信号**：是否接入、是否被 daemon 使用（`chronyc sourcestats`）
5. **重点检查时段日志**：2026-09-10 16:01~16:14（UTC+8）前后应有 step/fallback/失锁记录，可定位恶化事件
6. **修复后验证**：可复用本目录 `monitor_ntp.py`（`python3 monitor_ntp.py 1800 5`）+ `analyze_ntp.py` 做修复前后对比

### 2.6 固件代码分析与修复（2026-09-10）

**服务器固件已开源**：`github.com/luweixuancl/esp32c3-gnss-ntp`（原名 `Acode_test`，2026-09-14 更名，旧地址 301 重定向；下文涉及的历史分支现已清理），分支 `cursor/esp32c3-status-leds-5075`。硬件：合宙 CORE ESP32-C3 + DX-GP22 GNSS（1PPS + NMEA@9600）+ SSD1306 + KY-040。本地已 clone 并新建修复分支 `fix/time-alignment`（3 个提交），补丁导出于 `patches/`。

**实测现象 ↔ 代码缺陷精确对应：**

| 实测现象 | 代码缺陷 | 位置 |
|---|---|---|
| 周期性 **-980ms**（每30~45s，1~3轮） | `nowUtc()` 假设"NMEA 时间=当前 PPS 秒"直接使用，但 RMC(T) 语句在 9600 波特率下比 PPS(T) 边沿晚 ~100~800ms 到达并解析。窗口内 `utcEpoch` 还是上一秒 → 返回时间恰好旧 ~1s | `gps_service.cpp nowUtc()` |
| **-3~-4s** 持续失步（最长344s） | 主循环阻塞叠加：WiFi 同步连接（≤20s delay 循环）、同步扫描（2~5s）、OLED I2C 默认 100kHz 全帧 ~100ms/250ms、`delay(500)`；UART RX 缓冲仅 256B（~260ms 就溢出）→ NMEA 丢帧，时间停更 | `wifi_manager.cpp / main.cpp / display_ui.cpp` |
| 客户端无法识别坏样本 | 时间过期照样应答：无新鲜度检查、LI 恒 0、root dispersion 恒 0 | `gps_service.cpp / ntp_server.cpp` |

**修复内容（fix/time-alignment 分支）：**

| 提交 | 内容 |
|---|---|
| `a4c186e` fix(gps) | **PPS 计数对齐算法**：NMEA 提交时快照单调 `ppsCount_`，查询时 `lag = 当前计数 − 提交计数` = 该语句落后的 PPS 秒数，`baseSec = utcEpoch + lag` —— 对任意解析延迟（1s 竞态 / 多秒积压）都精确；仅解析到新秒值才提交（防旧值刷新失效新鲜度）；`commitMs` 超 3s 视为流停滞拒绝服务；RX 缓冲 256B→2048B（可吸收 ~2.1s 阻塞） |
| `dbf9d23` fix(ntp) | 元数据诚实化：时间不可用 → LI=3 + stratum 16；root dispersion 由 `qualityMs` 动态计算（客户端可据此丢弃坏样本）；precision 分级（PPS 锚定 -10 / 插值 -6）；Reference 时间戳 = PPS 锚定整秒 |
| `ea7d315` refactor | 主循环去阻塞：WiFi 连接改非阻塞状态机（`beginConnect`/`pollConnect`）、扫描异步化（UI 可取消）、删除 `delay(500)`、OLED I2C 提速 400kHz（帧耗时 100ms→25ms）；Web 配置页保留阻塞封装（仅 AP 模式使用） |

**遗留与验收：**
- 本机无 PlatformIO 交叉编译环境，固件**未经编译验证**，烧录前建议本地 `pio run` 检查
- **验收流程**：烧录后运行 `python3 monitor_ntp.py 1800 5 && python3 analyze_ntp.py`，目标：配对差中位数 \|diff\| < 50ms、std < 30ms、异常率 < 2%（修复前基线：51.3%，数据见 2.5 节 CSV）
- 风险提示：若 -3~-4s 失步主因是 DX-GP22 模块自身失锁（而非固件），固件修复后 LI=3 会如实暴露该状态 → OLED/LED 可直接观察（D5 灯：常亮=Stratum-1 ready，闪烁=有定位无 PPS）

### 2.7 RTOS 三任务化架构（2026-09-10，分支 feat/rtos-tasks）

**背景**：ESP32-C3 Arduino 本身运行在 FreeRTOS 上（`loop()` 只是优先级 1 的 loopTask），2.6 靠"每个调用点都不阻塞"的纪律保证时间链路——新增功能可能破坏该纪律。任务化提供**抢占式隔离**，是授时设备的正统架构，作为第二步演进叠加在 fix/time-alignment 之上。

**任务架构：**

| 任务 | 优先级 | 栈 | 职责（独占资源） |
|---|---|-----|---|
| `task-time` | 5 | 6KB | NMEA 解析（独占 UART）、PPS 处理、NTP 应答（独占 UDP 123）、订阅 `esp_task_wdt` |
| `task-net` | 2 | 8KB | WiFi 连接/扫描状态机、Web Portal（其阻塞式扫描不再波及授时） |
| `task-ui` | 1 | 4KB | OLED、旋钮、LED（原 loopTask 删除，三任务接管） |

**同步设计（无应用层互斥锁竞争，纯所有权隔离）：**
- **TimeSnapshot**：`GpsStatus` 由 task-time 独占写入，其他任务经 `snapshot()` 在 portMUX 临界区取副本（<1µs）——消灭跨任务共享竞争
- **PPS 唤醒**：ISR `vTaskNotifyGiveFromISR` 直接唤醒 task-time（微秒级、抖动最小），1ms 兜底 tick 覆盖 UDP 轮询
- **跨任务请求**：UI→net 走 `NetRequest` 队列（WiFi 连接/扫描/静态 IP/启动 Portal），替代原 pending 标志（消除 String 竞态）；net→UI 消息走 `gUiMsgQueue`
- **gSettings 统一互斥锁**：所有读改写（时区/静态 IP/Portal 保存）持锁进行
- **优先级红线**：应用任务 ≤5，低于 WiFi/lwIP 内部任务（~18-23），防协议栈饿死

**边界与验收：**
- RTOS 解决"软件阻塞/优先级"问题，**不解决 GPS 模块自身失锁**（2.6 风险提示仍有效）
- 验收指标与 2.6 相同（异常率 <2%、\|配对差中位数\|<50ms、std<30ms），另可观察 PPS 唤醒延迟抖动作为附加指标
- A/B 归因：fix/time-alignment（算法修复）与 feat/rtos-tasks（架构修复）可分别烧录对比
- 本机无编译环境，烧录前需 `pio run` 检查；补丁 `patches/0004-feat-rtos-time-net-ui.patch`

### 2.8 分支交付与远程推送状态（2026-09-10）

**本地仓库状态**（`/tmp/opencode/Acode_test`）：
- `fix/time-alignment` = 原分支 + 3 个修复提交（`a4c186e` → `ea7d315`）
- `feat/rtos-tasks` = fix/time-alignment + RTOS 任务化（`7d32adf`）

**本机直推 GitHub 不可行，双重阻塞：**
1. **网络**：`github.com` 直连完全超时（000/8s），而全局 gitconfig 的 `insteadOf` 规则把所有 github.com URL 劫持到 gh-proxy 只读镜像（fetch 可用，**push 不支持**）
2. **认证**：本机无 PAT / SSH 密钥 / credential helper

**交付物（已生成，位于本项目目录）：**
- `Acode_test_branches.bundle`（5MB）：两分支完整历史，可完整重建精确提交
- `patches/0001~0004`：四个补丁，可 `git am` 到上游分支重建（内容一致，哈希略有差异）

**在有权限的电脑上推送（二选一）：**

方案一 · bundle（推荐，保留精确提交）：
```bash
git clone -b fix/time-alignment Acode_test_branches.bundle repo && cd repo
git remote set-url origin https://github.com/luweixuancl/Acode_test.git
git push origin fix/time-alignment feat/rtos-tasks
```

方案二 · patches：
```bash
git clone -b cursor/esp32c3-status-leds-5075 https://github.com/luweixuancl/Acode_test.git && cd Acode_test
git checkout -b fix/time-alignment
git am 0001-fix-gps-PPS-NMEA-1s.patch 0002-fix-ntp.patch 0003-refactor-main-wifi-ui.patch
git push origin fix/time-alignment
git checkout -b feat/rtos-tasks
git am 0004-feat-rtos-time-net-ui.patch
git push origin feat/rtos-tasks
```

**状态**：⏳ 待推送。推送成功后本报告记录远程分支链接。

---

## 3. 背景知识：Android 时间同步机制

由系统服务 `NetworkTimeUpdateService` 实现：

| 项目 | 默认值 |
|---|---|
| NTP 服务器 | `time.android.com` |
| 周期性同步 | 约 24 小时一次 |
| 网络切换/重连/开机 | 触发尝试同步（网络可用后 ~3 秒） |
| 校时阈值 | 偏差 > 2 秒才实际调整 |
| 失败重试 | 约 5 分钟一次 |

**本机 600 ms 的偏差 < 2 秒阈值，系统不会校准**，会长期保持。设备晶振每天漂移几~几十 ms，积累到 2 秒才触发校正。

强制触发一次同步（Android 10+，不改服务器）：
```bash
adb shell cmd network_time_update_service force-refresh
```

---

## 4. 待办 / 下一步方案（未实施）

- [ ] **方案 A**：让安卓设备改用 `10.81.127.143` 校时 → **取消：2.5 长时监测证明该服务器异常率 51.3% 且恶化中，不可用**
- [ ] **方案 B**：改用 `ntp.aliyun.com` 等公共 NTP 校时（精度 ~5ms，实测极稳）
- [x] **方案 C**：GPS vs ntp.aliyun.com 30 次交替采样，输出更严格的精度统计对比（结果见 2.4）
- [ ] **方案 D**：向服务器管理员提交 2.5/2.6 节证据链与修复代码（`patches/`），跟踪烧录验证
- [x] **方案 E**：30 分钟长时监测，量化异常频率/持续时间/演化（结果见 2.5）
- [x] **方案 F（代码侧）**：固件病因定位 + fix/time-alignment 分支修复（见 2.6），待烧录
- [ ] **后续 G**：固件烧录后复测（`monitor_ntp.py` 30 分钟 + `analyze_ntp.py`），异常率 <2% 且 \|配对差中位数\|<50ms 方可恢复方案 A
- [x] **方案 H（代码侧）**：RTOS 三任务化 feat/rtos-tasks 分支（见 2.7），可与 2.6 版本 A/B 对比烧录
- [ ] **后续 I**：远程推送 fix/time-alignment 与 feat/rtos-tasks 分支（见 2.8：本机网络/认证双重受限，需在有权限电脑上经 bundle 或 patches 推送）

---

## 5. 更新日志

| 日期 | 内容 |
|---|---|
| 2026-09-10 | 初版：连通性测试、30 次采样统计、GPS vs 公共 NTP 对比、Android 同步机制整理 |
| 2026-09-10 | 方案 C 完成（新增 2.4）：发现 GPS 服务器偶发 ~1s 时间戳异常；修正 2.2/2.3 跳变归因；暂缓方案 A；新增待办 D/E |
| 2026-09-10 | 方案 E 完成（新增 2.5）：30 分钟监测，异常率 51.3%（27 段 episode），幅度从 ~1s 恶化至 3~4s，判定服务器不可用；新增管理员排查建议；方案 A 取消，新增公共 NTP 校时建议与修复后复测流程 |
| 2026-09-10 | 新增 2.6 节：固件开源代码（Acode_test@esp32c3-status-leds-5075）病因定位——NMEA/PPS 秒对齐竞态（-1s）+ 主循环阻塞致 NMEA 丢帧（多秒失步）；本地分支 fix/time-alignment 完成 3 项修复（PPS 计数对齐 / 元数据诚实化 / 主循环去阻塞），补丁见 patches/，待烧录复测 |
| 2026-09-10 | 新增 2.7 节：RTOS 三任务化（feat/rtos-tasks 分支）——time(5)/net(2)/ui(1) 抢占式隔离 + portMUX 快照 + 队列请求 + 统一设置锁；补丁 0004；与 2.6 可 A/B 对比烧录 |
| 2026-09-10 | 新增 2.8 节：分支交付与推送状态——本机直推不可行（github.com 超时 + 无凭证 + 代理只读），生成 bundle 与 4 个 patch 供外部推送，待办 I 跟踪 |
| 2026-09-15 | 进度注记：2.6/2.7 的修复均已合入主线并发布 v1.0.0（仓库更名 `esp32c3-gnss-ntp`，历史分支与旧 bundle 流程已由主干取代）；固件现状为 Stratum-1 长期稳定运行（LCK，residual 0ms），原始问题不再复现 |

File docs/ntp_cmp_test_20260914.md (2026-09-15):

# NTP 比对测试记录（2026-09-14，Termux vs 阿里云）

## 摘要

2026-09-14 用手机 Termux 对固件设备做了 **10 分钟、每 10 秒一轮** 的 NTP 比对（`tools/ntp_cmp_termux.py`）。结论：

- 脚本在 **搜星未锁定** 时就开跑：前 **5** 轮 `clock=ACQ`、stratum **16**、refid **`INIT`**、LI=3。此时 offset 约 −4×10¹² ms，是诚实的未同步时间，**不能计入精度**。
- 第 6 轮起进入 **`LCK`**（10:29:19 +08），之后 **55/55** 轮 stratum **1**、refid **`GPSS`**、`ppsFresh=true`、`residualMs=0`。
- 锁定后相对手机，offset 中位 **+24.00 ms**（手机系统钟慢约 24 ms）。含 Wi‑Fi 高 RTT 尖峰时 stdev ≈ **9.2 ms**；**delay < 20 ms** 的 46 轮 stdev ≈ **1.34 ms**、相邻步长中位 ≈ **0.98 ms**。
- 相对阿里云：成功配对 **52** 轮，`|GPS−阿里云|` 中位 **−6.6 ms**，范围 **−20.1～+28.8 ms**；**`|diff| > 50 / 100 / 400 ms`：0/52**。阿里云超时 3 次。
- **勿把「相对手机的 1.3～9 ms stdev」当成对 UTC 的绝对精度**；测法是手机 Wi‑Fi NTP，底噪已在数毫秒。

原始 CSV：[`docs/cmp_20260914_102829.csv`](cmp_20260914_102829.csv)（从 `ntp_cmp_20260914_102829_4253.csv` 归档）。

对比 2026-09-11（全程已锁定、Windows PC）：见 [ntp_cmp_test_20260911.md](ntp_cmp_test_20260911.md)。

---

## 测试条件

| 项 | 值 |
|----|-----|
| 日期 | 2026-09-14 10:28:29–10:38:19（**+08**） |
| 时长 / 间隔 | 600 s / 10 s → **60** 轮（含 5 轮 ACQ） |
| 设备 | ESP32-C3 GNSS NTP（`10.81.127.143`） |
| 客户端 | Termux 手机，与设备同一局域网 Wi‑Fi |
| 脚本 | `tools/ntp_cmp_termux.py`（标准库 UDP/123 + 读 `/status`） |
| 时钟状态 | 轮 1–5 **ACQ**；轮 6–60 **LCK**，`residualMs=0`，`ppsFresh=true` |
| GPS NTP（锁定后） | UDP/123，stratum **1**，LI=0，refid **GPSS** |
| 参考 | `ntp.aliyun.com` → `203.107.6.88`（stratum 2 或 3） |
| 指标定义 | `offset_ms`：经典 NTP「服务器相对本机」；`diff = gps_offset − ali_offset` |

统计锁定后精度时：**只使用 `clock=LCK` 且 `gps_stratum=1` 且 `gps_refid=GPSS` 的行。**

---

## 结果 0：搜星阶段（轮 1–5）

| 轮 | 本地时间 | clock | stratum | LI | refid | `/status` |
|----|---|---|---|----|---|---|
| 1–5 | 10:28:29–10:29:09 | ACQ | 16 | 3 | `INIT` | `ppsFresh=false`，`stratum1=false` |

未锁定时设备故意不报 GPS 时：offset 约 **−3.998×10¹² ms**（量级上等于「NTP 纪元/未同步」相对 2026 年的差），root dispersion **65535 s**。这是 Phase A 诚实元数据（unsync → LI=3 / stratum 16 / `INIT`），不是坏钟。

**复现建议：** 等 OLED / `ntpdate -q` 已是 stratum 1 再开脚本，曲线会干净很多。

---

## 结果 1：锁定后 GPS NTP ↔ 手机

`gps_offset_ms`（n=55，10:29:19–10:38:19）：

| 指标 | 全部 LCK (ms) | delay < 20 ms (ms) |
|---|---|---|
| n | 55 | **46** |
| median | **+24.00** | **+23.99** |
| mean | +27.18 | +24.21 |
| **stdev** | 9.16 | **1.34** |
| min / max | +4.33 / +61.12 | +21.71 / +29.83 |
| 相邻 \|Δ\| median | 1.52 | **0.98** |
| 相邻 \|Δ\| mean | 7.85 | 1.32 |
| max \|Δ\| | 37.34 | 7.58 |
| RTT delay median | 7.46 | ~6–8 |
| RTT delay max | 81.29 | < 20 |

约 **+24 ms** 的绝对偏差是 **手机系统钟相对 GPS/UTC 慢了约 24 ms**，不是模块误差。稳定性看 **stdev / 步长**。

9 次 offset 明显偏离 +24 ms 的行，delay 也同时升到 38–81 ms（见下表）。这是 **手机↔设备 Wi‑Fi 排队/重传**，不是 GNSS 秒跳。滤掉后 1.34 ms stdev 略好于 2026-09-11 PC 测的 2.63 ms。

锁定后 GPS offset 滑动窗（窗内 pstdev 再取平均）：

| 窗宽 | 约时长 | 全部 LCK (ms) | delay < 20 ms (ms) |
|---|---|---|---|
| 3 | 30 s | 5.40 | **0.83** |
| 6 | 60 s | 7.52 | **1.02** |
| 12 | 120 s | 8.28 | **1.26** |

全部 LCK 的滑动窗被高 RTT 尖峰抬高；干净样本才反映设备侧起伏。

锁定后 root dispersion 几乎恒为 **6.00 ms**（前 2 轮 LCK 为 4.99 ms）。

### 高 RTT / offset 尖峰（LCK）

| idx | 时间 | gps_offset (ms) | gps_delay (ms) | ali_offset (ms) | diff (ms) |
|-----|---|---|---|---|---|
| 8 | 10:29:39 | 49.68 | 61.94 | 36.91 | +12.77 |
| 14 | 10:30:39 | 48.90 | 63.65 | 30.35 | +18.55 |
| 15 | 10:30:49 | 41.49 | 41.68 | （超时） | — |
| 17 | 10:31:09 | 46.28 | 51.79 | 30.08 | +16.20 |
| 27 | 10:32:49 | 36.19 | 38.51 | 26.17 | +10.02 |
| 34 | 10:33:59 | 61.12 | 81.29 | 32.37 | +28.75 |
| 39 | 10:34:49 | 40.53 | 38.86 | 40.75 | −0.22 |
| 51 | 10:36:49 | 4.33 | 46.41 | （超时） | — |
| 55 | 10:37:29 | 52.63 | 68.98 | 35.01 | +17.62 |

#51 的 offset 落到 +4.3 ms 而 delay 仍高，是典型的 **不对称时延**（去程/回程不等），不能读成 GPS 回退了 20 ms。

---

## 结果 2：GPS vs 阿里云

锁定后阿里云成功 **52/55**；超时 3 次（#15、#37、#51，`timed out`）。云侧 stratum 在 **2**（32 次）与 **3**（20 次）之间切换。

相对手机的两条 offset 曲线（LCK 且阿里云成功）：

| 来源 | offset stdev (ms) | 相邻 \|Δ\| median (ms) | delay median (ms) | delay 范围 (ms) |
|---|---|---|---|---|
| **GPS 设备** | 8.63（含 Wi‑Fi 尖峰） | **1.27** | **7.5** | 5.3–81.3 |
| 阿里云 NTP | 6.33 | 6.64 | **65.1** | 45.0–103.5 |

`diff = GPS − 阿里云`（n=52）：

| 指标 | 值 (ms) |
|---|---|
| median | **−6.63** |
| mean | −3.65 |
| stdev | 10.03 |
| min / max | −20.08 / +28.75 |
| \|diff\| > 50 | **0 / 52** |
| \|diff\| > 100 | **0 / 52** |
| \|diff\| > 400 | **0 / 52** |

与 2026-09-11 不同：那次阿里云出现约 **+253 ms** 的路径尖峰（GPS 仍贴着本机基线）；本次云侧没有几百毫秒跳变，两边对 UTC 的粗一致性很好（约 ±20 ms）。

**结论：** 锁定后设备宜作 **局域网主时钟**。阿里云 delay 约 65 ms、stratum 2/3 会切，只适合粗参考。GPS 在干净 RTT 下比云更稳；含手机 Wi‑Fi 尖峰时 stdev 会被测法抬高，不要据此说「GPS 比阿里云抖」。

脚本参考门槛（`tools/ntp_cmp_termux.py`）：异常 `|diff|>400` < 2%、`|median|<50 ms` —— **本轮均通过**（异常 0/52，median −6.6 ms）。

---

## 与 2026-09-11 对照

| 项 | 2026-09-11 | 2026-09-14 |
|----|---|---|
| 客户端 | Windows PC + Wi‑Fi | Termux 手机 + Wi‑Fi |
| 设备 IP | `192.168.124.6` | `10.81.127.143` |
| 开跑时时钟 | 全程 LCK | 先 ACQ 约 50 s，再 LCK |
| GPS offset median | −243 ms（PC 钟差） | +24 ms（手机钟差） |
| GPS stdev（宜引用） | 2.63 ms（全程 delay 都小） | **1.34 ms**（delay < 20 ms） |
| \|GPS−阿里云\| 最大 | +253 ms（云尖峰） | +29 ms |
| \|diff\| > 400 | 0/60 | 0/52 |

两次绝对 offset 差一个数量级，只说明 **两台客户端系统钟不一样**，不能横向比「谁更准」。

---

## 精度等级说明（产品定位）

| 说法 | 说明 |
|---|---|
| Stratum 1 / `GPSS` | 角色是「GNSS 主参考」，**不是**「误差 = 1 ms」 |
| 本测干净样本 stdev ~1.3 ms | **测量起伏**（手机 + Wi‑Fi NTP），易触碰测法底噪 |
| 商用机架 GPS NTP | 常宣传对 UTC **µs～百 µs**（有线 + 好客户端） |
| 本产品合理定位 | **局域网 Stratum-1 GNSS NTP**，客户端体验约 **1～10 ms** 量级；**非**电信/PTP/金融同步级 |

要宣称亚毫秒/微秒级，需 **PPS 对参考 PPS（示波器）** 或 **硬件时间戳有线 NTP**，不能单靠「手机 vs 阿里云」。

---

## 复现

设备已 STA，**建议已 LCK** 后再跑：

```bash
# Termux
pkg install python
curl -L -o ntp_cmp_termux.py \
  https://ghproxy.net/https://raw.githubusercontent.com/luweixuancl/esp32c3-gnss-ntp/main/tools/ntp_cmp_termux.py
python ntp_cmp_termux.py --gps 10.81.127.143 --minutes 10
```

手机请连与设备同一 2.4 GHz Wi‑Fi。CSV 写在当前目录（`ntp_cmp_YYYYMMDD_HHMMSS.csv`）。

分析本记录：

```bash
# 只统计 clock=LCK 且 stratum=1 的 gps_offset_ms / diff_gps_minus_ali_ms
# 原始表：docs/cmp_20260914_102829.csv
```

---

## 相关文档

- [clock_eval_two_ntp_cmp.md](clock_eval_two_ntp_cmp.md) — 两次比对 + 时钟算法评价  
- [ntp_cmp_test_20260911.md](ntp_cmp_test_20260911.md) — 2026-09-11 PC 比对  
- [local_clock_gps_check.md](local_clock_gps_check.md) — LocalClock / residual / Holdover  
- [wifi_event_fsm.md](wifi_event_fsm.md) — WiFi 事件与重连

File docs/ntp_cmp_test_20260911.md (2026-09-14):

# NTP 比对测试记录（GPS vs 本机 / 阿里云）

## 摘要

2026-09-11 对固件设备做了 **10 分钟、每 10 秒一轮** 的 NTP 比对。结论：

- 相对本机，**GPS 设备 offset 很稳**（stdev ≈ **2.6 ms**，相邻步长 median ≈ **1.1 ms**）。
- 相对阿里云，大 diff 主要来自 **云侧路径跳变**，不是 GPS 抖动。
- **`|GPS−阿里云| > 400 ms`：0/60**；全程 `clock=LCK`、stratum 1。
- **勿把「相对本机的 2.6 ms stdev」当成对 UTC 的绝对精度**；WiFi + PC 系统钟测法底噪通常已在数毫秒。

原始数据：`ntp_cmp_20260911_234802.csv`（仓库根目录，已被 `.gitignore` 忽略时可本地留存）。

---

## 测试条件

| 项 | 值 |
|----|-----|
| 日期 | 2026-09-11 23:48–23:58（本地时区） |
| 时长 / 间隔 | 600 s / 10 s → **60** 轮配对成功 |
| 设备 | ESP32-C3 GNSS NTP（`192.168.124.6`） |
| STA | `H3C_LuxYang`，HTTP `/status` 显示 `sta=true` |
| 时钟状态 | 全程 **LCK**，`residualMs=0`，`ppsFresh=true` |
| GPS NTP | UDP/123，stratum **1**，refid **GPSS** |
| 参考 | `ntp.aliyun.com`（公网） |
| 本机 | Windows PC，经 WiFi 查询双方 NTP offset |
| 指标定义 | `offset_ms`：经典 NTP 客户端估算的「服务器相对本机」；`diff = gps_offset − ali_offset` |

---

## 结果 1：GPS NTP ↔ 本机

`gps_offset_ms` 序列（n=60）：

| 指标 | 值 (ms) |
|---|---|
| median | −243.28 |
| mean | −243.55 |
| **stdev** | **2.63** |
| min / max | −256.81 / −239.83 |
| 相邻 \|Δ\| median | **1.11** |
| 相邻 \|Δ\| mean | 1.86 |
| 相邻 Δ stdev | 3.40 |
| max \|Δ\| | 13.19 |
| RTT delay median | 5.26 |

约 **−243 ms** 的绝对偏差主要是 **本机系统钟相对 UTC/GPS 的慢/快差**，不是模块抖动。  
稳定性应看 **stdev / 步长**，不看绝对 offset 大小。

滑动窗（对 offset 均值再求 stdev，越平滑越小）：

| 窗宽 | 约时长 | stdev (ms) |
|---|---|---|
| 3 | 30 s | ≈ 1.7 |
| 6 | 60 s | ≈ 1.4 |
| 12 | 120 s | ≈ 1.1 |

---

## 结果 2：GPS vs 阿里云（谁更稳）

相对本机的两条 offset 曲线：

| 来源 | offset stdev (ms) | 相邻 \|Δ\| median (ms) | max \|Δ\| (ms) |
|---|---|---|---|
| **GPS 设备** | **2.63** | **1.11** | 13.2 |
| 阿里云 NTP | 55.77 | 5.53 | ≈ 250 |

`diff = GPS − 阿里云`（n=60）：

| 指标 | 值 (ms) |
|---|---|
| median | −3.34 |
| mean | 8.46 |
| stdev | 56.07 |
| min / max | −20.11 / +252.93 |
| \|diff\| > 400 | **0 / 60** |

最大几次 \|diff\|（例如 +253 ms）对应阿里云 `offset` 落到约 **−490 ms**，GPS 仍停在约 **−242 ms** → **云路径偶发尖峰**。

**结论：本测法下 GPS 设备明显比阿里云更稳，宜作局域网主时钟；阿里云只适合粗参考。**

---

## 精度等级说明（产品定位）

| 说法 | 说明 |
|---|---|
| Stratum 1 / `GPSS` | 角色是「GNSS 主参考」，**不是**「误差 = 1 ms」 |
| 本测 GPS offset stdev ~2.6 ms | **测量起伏**（PC + WiFi NTP），易触碰测法底噪 |
| 商用机架 GPS NTP | 常宣传对 UTC **µs～百 µs**（有线 + 好客户端） |
| 本产品合理定位 | **局域网 Stratum-1 GNSS NTP**，客户端体验约 **1～10 ms** 量级；**非**电信/PTP/金融同步级 |

要宣称亚毫秒/微秒级，需 **PPS 对参考 PPS（示波器）** 或 **硬件时间戳有线 NTP**，不能单靠「笔记本 vs 阿里云」。

---

## 复现

```text
# 设备已 STA + LCK 后，对本机执行（示例）：
# 每 10s 查 GPS_IP 与 ntp.aliyun.com，写 CSV，持续 600s
# 字段含：gps_offset_ms, ali_offset_ms, diff_gps_minus_ali_ms, clock, residualMs, ppsFresh
```

分析脚本可参考 `tools/analyze_monitor_csv.py`（旧版 monitor 格式）或对 `ntp_cmp_*.csv` 用同等统计。

---

## 相关文档

- [clock_eval_two_ntp_cmp.md](clock_eval_two_ntp_cmp.md) — 两次比对 + 时钟算法评价  
- [ntp_cmp_test_20260914.md](ntp_cmp_test_20260914.md) — 2026-09-14 Termux 比对（含 ACQ→LCK）  
- [local_clock_gps_check.md](local_clock_gps_check.md) — LocalClock / residual / Holdover  
- [wifi_event_fsm.md](wifi_event_fsm.md) — WiFi 事件与重连

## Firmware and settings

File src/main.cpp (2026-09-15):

#include <Arduino.h>
#include <WiFi.h>
#include <esp_task_wdt.h>
#include <freertos/FreeRTOS.h>
#include <freertos/task.h>

#include "app_ipc.h"
#include "config.h"
#include "settings.h"
#include "gps_service.h"
#include "ntp_server.h"
#include "wifi_manager.h"
#include "web_portal.h"
#include "encoder.h"
#include "display_ui.h"
#include "status_leds.h"

SettingsStore gStore;
AppSettings gSettings;
GpsService gGps;
NtpServer gNtp;
WifiManager gWifi;
WebPortal gPortal;
EncoderInput gEnc;
DisplayUi gUi;
StatusLeds gLeds;

TaskHandle_t gTaskTime = nullptr;
TaskHandle_t gTaskNet = nullptr;
TaskHandle_t gTaskUi = nullptr;

enum class NetWork : uint8_t {
  Idle = 0,
  Connecting = 1,
  Scanning = 2,
  Probing = 3,
};

static NetWork gNetWork = NetWork::Idle;
static bool gScanUiPending = false;
static uint32_t gScanUiSeq = 0;
static uint32_t gScanWaitStartMs = 0;
static AppSettings gPendingSta;
static bool gStopApOnConnectOk = false;
static bool gBootNeedApIfFail = true;
static bool gConnectFromAutoReconnect = false;

// Survives ESP.restart() (soft reset), zeroed on real power-on: latches the
// factory reset so holding the switch through the auto-reboot cannot wipe
// the (already default) config again. One reset per power-on cycle.
RTC_DATA_ATTR static uint32_t gFactoryResetLatch = 0;

static bool startStaConnect(const AppSettings& settings, bool stopApOnOk) {
  if (gWifi.isBusy() || gNetWork != NetWork::Idle) {
    postUiText("WiFi busy");
    return false;
  }
  if (!gWifi.beginConnect(settings)) {
    postUiText("WiFi busy");
    return false;
  }
  gPendingSta = settings;
  gStopApOnConnectOk = stopApOnOk;
  gConnectFromAutoReconnect = false;
  gNetWork = NetWork::Connecting;
  postUiText("WiFi joining...");
  return true;
}

static void factoryResetNow() {
  Serial.println("[reset] FACTORY RESET: wiping settings namespace");
  gUi.bootMessage("Factory reset", "clearing...");
  gStore.reset();
  AppSettings def;  // all defaults; also writes fresh ver/crc
  gStore.save(def);
  Serial.println("[reset] config cleared - restarting");
  gUi.bootMessage("Config reset", "restarting...");
  gFactoryResetLatch = 1;  // next boot must not re-wipe if SW still held
  delay(800);
  ESP.restart();
}

// Cold-boot escape hatch: hold the encoder switch through power-on; after
// FACTORY_RESET_HOLD_MS every setting returns to defaults (new SoftAP flow).
static void checkFactoryReset() {
  const bool justReset = gFactoryResetLatch != 0;
  gFactoryResetLatch = 0;
  if (justReset) {
    Serial.println("[reset] skip: factory reset already ran this power cycle");
    return;
  }
  if (digitalRead(PIN_ENC_SW) != LOW) {
    return;  // normal boot (pullup is set by gEnc.begin())
  }
  Serial.println("[reset] SW held at boot - keep holding 3s to factory reset");
  gUi.bootMessage("Hold 3s = reset", "release = cancel");
  const uint32_t start = millis();
  while (digitalRead(PIN_ENC_SW) == LOW) {
    if (millis() - start >= FACTORY_RESET_HOLD_MS) {
      factoryResetNow();
      return;
    }
    delay(10);
  }
  Serial.println("[reset] released early - normal boot");
  gUi.bootMessage("ESP32-C3 NTP", "Booting...");
}

static void openSetupApIfNeeded(const char* uiMsg) {
  if (gWifi.isStaConnected() || gIpc.setupAp) {
    return;
  }
  gWifi.cancelAutoReconnect();
  String apPass;
  if (settingsLock(pdMS_TO_TICKS(50))) {
    apPass = effectiveSoftApPassword(gSettings);
    settingsUnlock();
  } else {
    apPass = derivedSoftApPassword();
  }
  gWifi.startSetupAp(apPass);
  gIpc.setupAp = true;
  postUiText(uiMsg != nullptr ? uiMsg : "AP setup mode");
}

static void sendScanUi(UiMsgType type, const char* text) {
  UiMsg msg{};
  msg.type = type;
  msg.seq = gScanUiSeq;
  if (text != nullptr) {
    strncpy(msg.text, text, sizeof(msg.text) - 1);
  }
  xQueueSend(gIpc.uiMsg, &msg, 0);
}

static bool scanCacheFresh(uint32_t maxAgeMs) {
  return gWifi.scanState() == WifiScanState::Done && !gWifi.lastScan().empty() &&
         static_cast<int32_t>(millis() - gWifi.lastHarvestMs()) < static_cast<int32_t>(maxAgeMs);
}

static void notifyScanToUi(const std::vector<WifiNetwork>& nets, bool ok);
static void tryStartPendingScan();

static void failScanUi(const char* why) {
  sendScanUi(UiMsgType::ScanFailed, why);
  Serial.printf("[wifi] scan → UI fail (%s)\n", why ? why : "");
  gScanUiPending = false;
  if (gNetWork == NetWork::Scanning) {
    gNetWork = NetWork::Idle;
  }
}

static void notifyScanToUi(const std::vector<WifiNetwork>& nets, bool ok) {
  if (!gScanUiPending && gNetWork != NetWork::Scanning) {
    return;
  }
  const std::vector<WifiNetwork>& src = (!ok || nets.empty()) ? gWifi.lastScan() : nets;
  // Empty list is a real SCAN_DONE (0 APs), not a start-time failure.
  if (ok || !src.empty()) {
    if (xSemaphoreTake(gIpc.scanMutex, pdMS_TO_TICKS(50)) == pdTRUE) {
      gIpc.scanResults = src;
      gIpc.scanReady = true;
      xSemaphoreGive(gIpc.scanMutex);
    }
    sendScanUi(UiMsgType::ScanResult, nullptr);
    Serial.printf("[wifi] scan → UI kept=%u\n", static_cast<unsigned>(src.size()));
    gScanUiPending = false;
    if (gNetWork == NetWork::Scanning) {
      gNetWork = NetWork::Idle;
    }
    return;
  }
}

static void logScanDeferOnce(const char* why) {
  static const char* last = nullptr;
  if (last == why) {
    return;
  }
  last = why;
  Serial.printf("[wifi] scan deferred (%s)\n", why);
}

static void tryStartPendingScan() {
  if (!gScanUiPending) {
    return;
  }

  if (gWifi.isScanRunning() || gWifi.scanState() == WifiScanState::Running) {
    if (gNetWork != NetWork::Scanning) {
      Serial.println("[wifi] OLED adopted in-flight scan");
    }
    gNetWork = NetWork::Scanning;
    return;
  }

  if (scanCacheFresh(WIFI_SCAN_CACHE_MS)) {
    Serial.printf("[wifi] scan → UI from cache kept=%u\n",
                  static_cast<unsigned>(gWifi.lastScan().size()));
    notifyScanToUi(gWifi.lastScan(), true);
    return;
  }

  if (gNetWork == NetWork::Probing || gWifi.isProbeRunning()) {
    logScanDeferOnce("probe");
    return;
  }

  // Do not abortJoin: kicking a live/soon-to-be-live STA makes OLED fail
  // immediately, then SCAN_DONE arrives after GOT_IP from a later scan.
  if (gNetWork == NetWork::Connecting || (gWifi.isConnecting() && !gWifi.isStaConnected())) {
    logScanDeferOnce("STA joining");
    return;
  }

  if (gWifi.startScan()) {
    gNetWork = NetWork::Scanning;
    return;
  }

  logScanDeferOnce("busy");
}

static void driveScan() {
  if (gScanUiPending && gScanWaitStartMs != 0 &&
      static_cast<int32_t>(millis() - gScanWaitStartMs) >=
          static_cast<int32_t>(WIFI_SCAN_UI_TIMEOUT_MS)) {
    if (!gWifi.lastScan().empty()) {
      notifyScanToUi(gWifi.lastScan(), true);
    } else if (!gWifi.isScanRunning()) {
      failScanUi("timeout");
    }
  } else if (gScanUiPending && gNetWork != NetWork::Scanning && !gWifi.isScanRunning()) {
    tryStartPendingScan();
  }

  const bool need = gNetWork == NetWork::Scanning || gWifi.isScanRunning() ||
                    gWifi.peekScanDone() || gWifi.scanState() == WifiScanState::Running;
  if (!need) {
    return;
  }
  std::vector<WifiNetwork> nets;
  const WifiScanState st = gWifi.pollScan(&nets);
  if (st == WifiScanState::Running) {
    return;
  }
  if (st == WifiScanState::Done || !gWifi.lastScan().empty()) {
    notifyScanToUi(nets, true);
    return;
  }
  // Failed/Idle with nothing to show: retry, do not fail before SCAN_DONE.
  if (gScanUiPending) {
    if (gNetWork == NetWork::Scanning) {
      gNetWork = NetWork::Idle;
    }
    Serial.println("[wifi] scan empty/fail — retry");
    tryStartPendingScan();
  }
}

static void finishConnect(WifiConnectState st) {
  gNetWork = NetWork::Idle;
  const bool fromAuto = gConnectFromAutoReconnect;
  gConnectFromAutoReconnect = false;

  if (st == WifiConnectState::Connected) {
    char buf[48];
    snprintf(buf, sizeof(buf), "OK %s", gWifi.localIp().toString().c_str());
    postUiText(buf);
    Serial.printf("STA IP: %s  (http://%s/)\n", gWifi.localIp().toString().c_str(),
                  gWifi.localIp().toString().c_str());
    // STA is up — SoftAP must go away (was escape hatch only).
    gWifi.stopAp();
    gIpc.setupAp = false;
    gBootNeedApIfFail = false;
  } else if (fromAuto) {
    // Backoff retry continues inside WifiManager; SoftAP only on give-up.
    postUiText("WiFi retry...");
  } else {
    postUiText("WiFi failed");
    // Boot: do not open SoftAP on the first 201 — schedule reconnect instead.
    if (gBootNeedApIfFail && !gPendingSta.wifiSsid.isEmpty()) {
      gWifi.armReconnect(gPendingSta, WIFI_RECONNECT_BACKOFF_1_MS);
      Serial.println("[wifi] boot join failed → scheduled reconnect (SoftAP after give-up)");
      postUiText("WiFi retry...");
    } else if (gBootNeedApIfFail) {
      openSetupApIfNeeded("AP setup mode");
      gBootNeedApIfFail = false;
    }
  }
  gStopApOnConnectOk = false;
  tryStartPendingScan();
}

static void handleConnect(const char* ssid, const char* pass) {
  if (!settingsLock(pdMS_TO_TICKS(500))) {
    postUiText("Settings busy");
    return;
  }
  gSettings.wifiSsid = ssid;
  gSettings.wifiPass = pass;
  AppSettings copy = gSettings;
  settingsUnlock();
  gStore.save(copy);

  startStaConnect(copy, gIpc.setupAp);
}

static void handleNetRequest(const NetRequest& req) {
  switch (req.type) {
    case NetReqType::ConnectWifi:
      handleConnect(req.ssid, req.pass);
      break;
    case NetReqType::ScanWifi: {
      // Never ScanFailed here. Join-in-progress used to return "start fail"
      // before SCAN_DONE, which is what the OLED showed.
      gScanUiPending = true;
      gScanUiSeq = req.seq != 0 ? req.seq : (gScanUiSeq + 1);
      if (gScanUiSeq == 0) {
        gScanUiSeq = 1;
      }
      gScanWaitStartMs = millis();
      tryStartPendingScan();
      break;
    }
    case NetReqType::ApplyStaticIp: {
      if (!settingsLock(pdMS_TO_TICKS(200))) {
        postUiText("Settings busy");
        break;
      }
      AppSettings copy = gSettings;
      settingsUnlock();
      if (!gWifi.isStaConnected() && copy.wifiSsid.isEmpty()) {
        postUiText("Connect WiFi first");
      } else if (gNetWork != NetWork::Idle || gWifi.isBusy()) {
        postUiText("WiFi busy");
      } else if (!gWifi.isStaConnected()) {
        // No live STA to ARP-probe against; just try connect with static config.
        startStaConnect(copy, false);
      } else if (gWifi.localIp() == copy.staticIp) {
        // Current IP already is the requested static IP — keep the live link.
        postUiText("IP unchanged");
      } else if (!gWifi.beginConflictProbe(copy.staticIp)) {
        postUiText("Probe failed");
      } else {
        gPendingSta = copy;
        gNetWork = NetWork::Probing;
        postUiText("Checking IP...");
      }
      break;
    }
    case NetReqType::UseDhcp: {
      if (!settingsLock(pdMS_TO_TICKS(200))) {
        postUiText("Settings busy");
        break;
      }
      gSettings.useStaticIp = false;
      AppSettings copy = gSettings;
      settingsUnlock();
      gStore.save(copy);
      if (!copy.wifiSsid.isEmpty()) {
        startStaConnect(copy, false);
      }
      break;
    }
    case NetReqType::StartWebSetup: {
      String apPass;
      if (settingsLock(pdMS_TO_TICKS(50))) {
        apPass = effectiveSoftApPassword(gSettings);
        settingsUnlock();
      } else {
        apPass = derivedSoftApPassword();
      }
      gWifi.startSetupAp(apPass);
      gIpc.setupAp = true;
      break;
    }
  }
}

static void pollDisconnectAndReconnect() {
  // Radio may already have IP while FSM still thinks Failed (reason=8 race).
  if (gNetWork == NetWork::Idle && gWifi.healIfStaUp()) {
    char buf[48];
    snprintf(buf, sizeof(buf), "OK %s", gWifi.localIp().toString().c_str());
    postUiText(buf);
    gWifi.stopAp();
    gIpc.setupAp = false;
    gBootNeedApIfFail = false;
    Serial.printf("STA IP (healed): %s\n", gWifi.localIp().toString().c_str());
    tryStartPendingScan();
  }

  // Connecting owns DISC via pollConnect; elsewhere consume link-loss edges.
  // STA scan hops channels and often posts a transient DISC — do not steal the OLED.
  if (gNetWork != NetWork::Connecting && gNetWork != NetWork::Scanning) {
    uint16_t discReason = 0;
    if (gWifi.consumeDisconnect(&discReason)) {
      char buf[40];
      snprintf(buf, sizeof(buf), "WiFi lost (%u)", discReason);
      postUiText(buf);
    }
  } else if (gNetWork == NetWork::Scanning) {
    gWifi.consumeDisconnect(nullptr);
  }

  if (gWifi.consumeReconnectGiveUp()) {
    if (gWifi.isStaConnected()) {
      // Give-up raced with a live link — keep STA, do not SoftAP.
      gWifi.healIfStaUp();
      gBootNeedApIfFail = false;
    } else if (gBootNeedApIfFail || !gIpc.setupAp) {
      openSetupApIfNeeded("AP setup mode");
      gBootNeedApIfFail = false;
    }
  }

  if (gNetWork != NetWork::Idle) {
    return;
  }

  AppSettings recon;
  if (gWifi.pollAutoReconnect(&recon)) {
    gPendingSta = recon;
    gStopApOnConnectOk = gIpc.setupAp;
    gConnectFromAutoReconnect = true;
    gNetWork = NetWork::Connecting;
    postUiText("WiFi rejoin...");
  }
}

static void pollNetWork() {
  pollDisconnectAndReconnect();

  switch (gNetWork) {
    case NetWork::Connecting: {
      const WifiConnectState st = gWifi.pollConnect();
      if (st == WifiConnectState::Connecting) {
        break;
      }
      finishConnect(st);
      break;
    }
    case NetWork::Probing: {
      const WifiProbeState st = gWifi.pollConflictProbe();
      if (st == WifiProbeState::Running) {
        break;
      }
      gNetWork = NetWork::Idle;
      if (st == WifiProbeState::Conflict) {
        postUiText("IP CONFLICT!");
        Serial.printf("IP conflict on %s\n", gPendingSta.staticIp.toString().c_str());
      } else if (st == WifiProbeState::Clear) {
        startStaConnect(gPendingSta, false);
      } else {
        postUiText("Probe failed");
      }
      break;
    }
    case NetWork::Scanning:
    case NetWork::Idle:
    default:
      break;
  }
}

static void taskTime(void* /*arg*/) {
  esp_task_wdt_add(nullptr);
  gGps.setTimeTask(xTaskGetCurrentTaskHandle());
  ipcKickTime();

  // Cache last successful settings read so a busy mutex never looks like Refuse
  // and aborts Holdover mid-flight.
  AnomalyPolicy cachedPolicy = AnomalyPolicy::Refuse;
  uint16_t cachedHoldSec = CLK_HOLDOVER_SHORT_SEC;
  bool cachedTempComp = false;
  int16_t cachedTempCoeff = CLK_TEMP_COEFF_CENTI;
  NtpAclSnapshot cachedAcl;
  if (settingsLock(pdMS_TO_TICKS(100))) {
    cachedPolicy = gSettings.anomalyPolicy;
    cachedHoldSec = gSettings.holdoverSec;
    cachedTempComp = gSettings.tempComp;
    cachedTempCoeff = gSettings.tempCoeffCenti;
    cachedAcl.mode = gSettings.ntpAclMode;
    cachedAcl.count = gSettings.ntpAclCount;
    if (cachedAcl.count > NTP_ACL_MAX_ENTRIES) {
      cachedAcl.count = NTP_ACL_MAX_ENTRIES;
    }
    for (uint8_t i = 0; i < cachedAcl.count; ++i) {
      cachedAcl.ips[i] = static_cast<uint32_t>(gSettings.ntpAcl[i]);
    }
    settingsUnlock();
  }
  gNtp.setAcl(cachedAcl);
  gGps.setTempComp(cachedTempComp, cachedTempCoeff);

  for (;;) {
    ulTaskNotifyTake(pdTRUE, pdMS_TO_TICKS(1));

    if (settingsLock(0)) {
      cachedPolicy = gSettings.anomalyPolicy;
      cachedHoldSec = gSettings.holdoverSec;
      cachedTempComp = gSettings.tempComp;
      cachedTempCoeff = gSettings.tempCoeffCenti;
      cachedAcl.mode = gSettings.ntpAclMode;
      cachedAcl.count = gSettings.ntpAclCount;
      if (cachedAcl.count > NTP_ACL_MAX_ENTRIES) {
        cachedAcl.count = NTP_ACL_MAX_ENTRIES;
      }
      for (uint8_t i = 0; i < cachedAcl.count; ++i) {
        cachedAcl.ips[i] = static_cast<uint32_t>(gSettings.ntpAcl[i]);
      }
      settingsUnlock();
      gNtp.setAcl(cachedAcl);
      gGps.setTempComp(cachedTempComp, cachedTempCoeff);
    }

    gGps.loop(cachedPolicy, cachedHoldSec);
    gNtp.loop(gGps);

#if NTP_STATUS_LOG_MS > 0
    {
      static uint32_t lastLogMs = 0;
      const uint32_t now = millis();
      if (lastLogMs == 0 || (now - lastLogMs) >= NTP_STATUS_LOG_MS) {
        lastLogMs = now;
        const GpsStatus st = gGps.snapshot();
        Serial.printf(
            "[ntp] req=%lu served=%lu RATE=%lu DENY=%lu drop=%lu aclDeny=%lu "
            "clients=%u acl=%s/%u clk=%s T=%.1f dppm=%.2f\n",
            static_cast<unsigned long>(gNtp.requestCount()),
            static_cast<unsigned long>(gNtp.servedCount()),
            static_cast<unsigned long>(gNtp.rateLimitedCount()),
            static_cast<unsigned long>(gNtp.deniedCount()),
            static_cast<unsigned long>(gNtp.droppedCount()),
            static_cast<unsigned long>(gNtp.aclDeniedCount()),
            static_cast<unsigned>(gNtp.activeClientCount()),
            ntpAclModeMenuLabel(gNtp.aclMode()), static_cast<unsigned>(gNtp.aclCount()),
            clockStateLabel(st.clockState), static_cast<double>(st.tempC),
            static_cast<double>(st.tempCorrPpm));
      }
    }
#endif

    ipcKickTime();
    esp_task_wdt_reset();
  }
}

static void taskNet(void* /*arg*/) {
  esp_task_wdt_add(nullptr);
  ipcKickNet();

  AppSettings boot;
  if (settingsLock(pdMS_TO_TICKS(500))) {
    boot = gSettings;
    settingsUnlock();
  }

  gWifi.setAutoReconnect(boot.autoReconnect);

  // Start HTTP early so SoftAP/STA pages stay responsive during connect.
  gPortal.begin(&gWifi, &gGps, &gNtp);

  if (!boot.wifiSsid.isEmpty()) {
    gBootNeedApIfFail = true;
    if (!gWifi.beginConnect(boot)) {
      // Never open SoftAP just because begin was busy — keep trying saved WiFi.
      gWifi.armReconnect(boot, WIFI_RECONNECT_BACKOFF_1_MS);
      gPendingSta = boot;
      postUiText("WiFi retry...");
      Serial.println("[wifi] boot beginConnect deferred → reconnect armed (keep SoftAP off)");
    } else {
      gPendingSta = boot;
      gNetWork = NetWork::Connecting;
      postUiText("WiFi joining...");
    }
  } else {
    String apPass = effectiveSoftApPassword(boot);
    gWifi.startSetupAp(apPass);
    gIpc.setupAp = true;
    postUiText("AP setup mode");
    gBootNeedApIfFail = false;
  }

  for (;;) {
    // Harvest SCAN_DONE before any new scanNetworks() (which scanDelete()s).
    driveScan();

    NetRequest req;
    while (xQueueReceive(gIpc.netReq, &req, 0) == pdTRUE) {
      handleNetRequest(req);
    }

    String ssid, pass;
    if (gPortal.consumeConnectRequest(ssid, pass)) {
      handleConnect(ssid.c_str(), pass.c_str());
    }

    driveScan();
    pollNetWork();
    gPortal.loop();
    static uint8_t heapLowStreak = 0;
    if (ESP.getFreeHeap() < HEAP_RESTART_BYTES) {
      if (++heapLowStreak >= HEAP_RESTART_SAMPLES) {
        Serial.printf("[net] heap low (%u) x%u — restart\n",
                      static_cast<unsigned>(ESP.getFreeHeap()), heapLowStreak);
        delay(100);
        ESP.restart();
      }
    } else {
      heapLowStreak = 0;
    }
    ipcKickNet();
    esp_task_wdt_reset();
    vTaskDelay(pdMS_TO_TICKS(5));
  }
}

static void taskUi(void* /*arg*/) {
  esp_task_wdt_add(nullptr);
  ipcKickUi();
  for (;;) {
    gEnc.loop();
    const GpsStatus st = gGps.snapshot();
    ipcKickUi();
    gLeds.loop(gIpc.setupAp, gWifi.isStaConnected(), st);
    gUi.loop(gEnc, gGps, gWifi, gNtp);
    esp_task_wdt_reset();
    vTaskDelay(pdMS_TO_TICKS(10));
  }
}

void setup() {
  Serial.begin(115200);
  delay(200);
  Serial.println("\nESP32-C3 GNSS NTP Server (RTOS)");

  if (!ipcInit()) {
    Serial.println("IPC init failed — halt/restart");
    pinMode(PIN_LED_D4, OUTPUT);
    pinMode(PIN_LED_D5, OUTPUT);
    for (int i = 0; i < 50; ++i) {
      digitalWrite(PIN_LED_D4, i & 1);
      digitalWrite(PIN_LED_D5, !(i & 1));
      delay(100);
    }
    ESP.restart();
  }

  gStore.begin();

  gEnc.begin();
  gLeds.begin();
  gUi.begin();
  checkFactoryReset();  // hold SW 3s at power-on → wipe all settings, reboot

  gSettings = gStore.load();

  gGps.begin();
  gWifi.begin();
  gNtp.begin();

  Serial.printf("MAC=%s\n", WiFi.macAddress().c_str());
  Serial.printf("SoftAP default pass=%s (NVS appw overrides if set)\n",
                derivedSoftApPassword().c_str());

  // Priority: time=5 > net=2 > ui=1 (all below WiFi/lwIP ~18+)
  xTaskCreatePinnedToCore(taskTime, "task-time", 6144, nullptr, 5, &gTaskTime, 0);
  xTaskCreatePinnedToCore(taskNet, "task-net", 8192, nullptr, 2, &gTaskNet, 0);
  xTaskCreatePinnedToCore(taskUi, "task-ui", 4096, nullptr, 1, &gTaskUi, 0);

  Serial.println("Tasks started: time=5 net=2 ui=1");
}

void loop() {
  // Arduino loopTask is unused after RTOS refactor.
  vTaskDelete(nullptr);
}

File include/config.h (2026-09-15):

#pragma once

// ---------------------------------------------------------------------------
// Hardware wiring (合宙 CORE ESP32-C3 + DX-GP22 + SH1107/SSD1107 OLED + KY-040)
// Adjust these pins if your carrier board differs.
// ---------------------------------------------------------------------------

// UART0 (合宙 CORE / CH343): GPIO20 RX, GPIO21 TX — debug via Serial @ 115200
// DX-GP22 GNSS on UART1 (board UART1_RX=GPIO1, UART1_TX=GPIO0; 9600 8N1; 1PPS after fix)
#define PIN_GPS_RX           1   // ESP32 RX <- GP22 TXD  (UART1_RX)
#define PIN_GPS_TX           0   // ESP32 TX -> GP22 RXD  (UART1_TX)
#define PIN_GPS_PPS          4   // 1PPS input
#define GPS_UART_BAUD     9600
#define GPS_UART_NUM         1
#define GPS_DEBUG            0   // 1 = 每秒向 UART0 打印定位/PPS（time 任务内，默认关）
#define GPS_DEBUG_NMEA       0   // 1 = 把 NMEA 原文转发到 UART0

// SH1107 / SSD1107 0.96" 64x128 OLED over I2C (native portrait; setRotation(1) → 128x64 UI)
#define PIN_OLED_SDA         8
#define PIN_OLED_SCL        10
#define OLED_I2C_ADDR     0x3C
#define OLED_WIDTH          64
#define OLED_HEIGHT        128
#define OLED_ROTATION        1   // 1 = landscape UI on portrait panel

// KY-040 rotary encoder
#define PIN_ENC_A            2
#define PIN_ENC_B            3
#define PIN_ENC_SW           5
// Soft layer (task-ui): one detent ≈ 4 quadrature edges; leftover bounce is dropped.
#define ENC_DETENT_STEPS            4
#define ENC_IDLE_CLEAR_MS          80   // rest this long → clear sub-detent remainder
#define ENC_MIN_STEP_MS            50   // min gap between UI ticks (smooth, not bursty)
#define ENC_ISR_DEBOUNCE_US       250   // ISR edge floor; Gray table rejects 2-bit jumps

// On-board LEDs on 合宙 CORE ESP32 (datasheet 表4-1): D4=IO12, D5=IO13, active HIGH
#define PIN_LED_D4          12   // D4 RUN / WiFi
#define PIN_LED_D5          13   // D5 GPS / PPS / NTP ready

// SoftAP for web WiFi setup (SSID prefix). Password default: NTP-<MAC low 16-bit hex>.
#define AP_SSID_PREFIX      "NTP-Setup"
// Deprecated fixed password — B2 uses derivedSoftApPassword() / NVS `appw`.
#define AP_PASSWORD_LEGACY  "12345678"

// NTP
#define NTP_UDP_PORT         123
#define NTP_EPOCH_DELTA   2208988800UL  // 1900 -> 1970
// B1 rate limit / Kiss-o'-Death (task-time only; static client table)
#define NTP_CLIENT_SLOTS              12
#define NTP_RATE_PER_IP_PER_SEC        4
#define NTP_GLOBAL_RATE_PER_SEC       32
#define NTP_RATE_WINDOW_MS          1000
#define NTP_RATE_TO_DENY_MS        10000  // sustained over-limit → DENY cooldown
#define NTP_DENY_COOLDOWN_MS       60000
#define NTP_MAX_PACKETS_PER_LOOP       8
// B3 ACL AllowList (exact IPv4; Off by default)
#define NTP_ACL_MAX_ENTRIES            8
// B4: periodic UART0 summary from task-time (0 = off)
#define NTP_STATUS_LOG_MS          60000
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

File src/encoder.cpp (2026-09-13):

#include "encoder.h"
#include <esp_timer.h>

volatile int16_t EncoderInput::rotateAccum_ = 0;
volatile uint8_t EncoderInput::abState_ = 0;

// ISR-safe edge floor (µs). Finer filtering is in drainRawToFilter / consumeRotate.
static constexpr uint32_t kEncDebounceUs = ENC_ISR_DEBOUNCE_US;

// Quadrature transition table indexed by (prev<<2)|curr; values -1/0/+1.
// prev/curr are 2-bit Gray codes: bit1=A, bit0=B.
static const int8_t kQuadTable[16] = {
    0, -1, +1, 0,  // 00 -> 00,01,10,11
    +1, 0, 0, -1,  // 01 -> 00,01,10,11
    -1, 0, 0, +1,  // 10 -> 00,01,10,11
    0, +1, -1, 0,  // 11 -> 00,01,10,11
};

void IRAM_ATTR EncoderInput::onEncIsr() {
  static uint64_t lastUs = 0;
  const uint64_t nowUs = esp_timer_get_time();
  if (nowUs - lastUs < kEncDebounceUs) {
    return;
  }
  lastUs = nowUs;

  const uint8_t a = digitalRead(PIN_ENC_A) ? 1 : 0;
  const uint8_t b = digitalRead(PIN_ENC_B) ? 1 : 0;
  const uint8_t curr = static_cast<uint8_t>((a << 1) | b);
  const uint8_t prev = abState_;
  if (curr == prev) {
    return;
  }

  const int8_t step = kQuadTable[(prev << 2) | curr];
  abState_ = curr;
  if (step == 0) {
    return;
  }

  const int16_t next = static_cast<int16_t>(rotateAccum_ + step);
  if (next > 32000 || next < -32000) {
    return;
  }
  rotateAccum_ = next;
}

void EncoderInput::begin() {
  pinMode(PIN_ENC_A, INPUT_PULLUP);
  pinMode(PIN_ENC_B, INPUT_PULLUP);
  pinMode(PIN_ENC_SW, INPUT_PULLUP);

  const uint8_t a = digitalRead(PIN_ENC_A) ? 1 : 0;
  const uint8_t b = digitalRead(PIN_ENC_B) ? 1 : 0;
  abState_ = static_cast<uint8_t>((a << 1) | b);

  attachInterrupt(digitalPinToInterrupt(PIN_ENC_A), onEncIsr, CHANGE);
  attachInterrupt(digitalPinToInterrupt(PIN_ENC_B), onEncIsr, CHANGE);
}

void EncoderInput::loop() {
  sampleButton();
  drainRawToFilter();
}

void EncoderInput::drainRawToFilter() {
  noInterrupts();
  const int16_t raw = rotateAccum_;
  rotateAccum_ = 0;
  interrupts();

  const uint32_t now = millis();
  if (raw != 0) {
    int32_t next = static_cast<int32_t>(filtAccum_) + raw;
    if (next > 32000) {
      next = 32000;
    } else if (next < -32000) {
      next = -32000;
    }
    filtAccum_ = static_cast<int16_t>(next);
    lastMotionMs_ = now;
    return;
  }
  if (filtAccum_ != 0 &&
      static_cast<int32_t>(now - lastMotionMs_) >= static_cast<int32_t>(ENC_IDLE_CLEAR_MS) &&
      abs(filtAccum_) < ENC_DETENT_STEPS) {
    filtAccum_ = 0;
  }
}

void EncoderInput::sampleButton() {
  bool down = digitalRead(PIN_ENC_SW) == LOW;
  uint32_t now = millis();
  if (down && !btnDown_) {
    btnDown_ = true;
    pressStartMs_ = now;
  } else if (!down && btnDown_) {
    btnDown_ = false;
    uint32_t held = now - pressStartMs_;
    if (held >= 800) {
      longPending_ = true;
    } else if (held >= 30) {
      clickPending_ = true;
    }
  } else if (down && btnDown_ && !longPending_ && (now - pressStartMs_ >= 800)) {
    longPending_ = true;
  }
}

int8_t EncoderInput::consumeRotate() {
  const int16_t th = static_cast<int16_t>(ENC_DETENT_STEPS);
  if (filtAccum_ < th && filtAccum_ > -th) {
    return 0;
  }

  const uint32_t now = millis();
  const bool fastSpin = abs(filtAccum_) >= (th * 2);
  if (!fastSpin && lastEmitMs_ != 0 &&
      static_cast<int32_t>(now - lastEmitMs_) < static_cast<int32_t>(ENC_MIN_STEP_MS)) {
    return 0;
  }

  if (filtAccum_ >= th) {
    filtAccum_ = static_cast<int16_t>(filtAccum_ - th);
    if (!fastSpin && abs(filtAccum_) < th) {
      filtAccum_ = 0;
    }
    lastEmitMs_ = now;
    return 1;
  }

  filtAccum_ = static_cast<int16_t>(filtAccum_ + th);
  if (!fastSpin && abs(filtAccum_) < th) {
    filtAccum_ = 0;
  }
  lastEmitMs_ = now;
  return -1;
}

bool EncoderInput::consumeClick() {
  if (clickPending_) {
    clickPending_ = false;
    return true;
  }
  return false;
}

bool EncoderInput::consumeLongPress() {
  if (longPending_) {
    longPending_ = false;
    clickPending_ = false;
    return true;
  }
  return false;
}

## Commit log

2026-06-15 Initial commit from Acode
    [Case_Ver2-BPanel.stl, Case_Ver2-Bottom.stl, Case_Ver2-FPanel.stl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]
2026-09-09 Reset repository to an empty project
    Remove all previous code and assets (GNSS time servers, ImGui,
    claude-code-rust, NTRIP tests, and misc files). Keep a minimal README
    so the repo can start clean.
    [Case_Ver2-BPanel.stl, Case_Ver2-Bottom.stl, Case_Ver2-FPanel.stl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]
2026-09-09 Add ESP32-C3 GNSS NTP server firmware
    Implement a PlatformIO Arduino project for ESP32-C3 with DX-GP22 GNSS,
    SSD1306 OLED status display, rotary-encoder menus, static IP conflict
    detection via ARP, WiFi scan/password entry, and a SoftAP web portal
    for WiFi setup. GPS-disciplined NTP replies on UDP/123 as stratum 1.
2026-09-10 Add D4/D5 status LEDs on GPIO12 and GPIO13.
    Drive the board's active-high LEDs to show WiFi/setup on D4 and GNSS/PPS lock on D5 so running state is visible without the OLED.
2026-09-10 Document Hezhou CORE ESP32 D4/D5 pin mapping.
    Match datasheet table 4-1: on-board D4=IO12 and D5=IO13, active high.
2026-09-10 Move GNSS UART to UART1 so UART0 can print debug.
2026-09-11 Fix boot WiFi: stop savePolicy wiping SSID to null and retry on 201.
    Policy-only /save no longer writes ArduinoJson null as SSID; corrupt
    NVS is cleared on load, and cold-boot NO_AP_FOUND keeps re-joining
    before SoftAP escape.
    [config.h, main.cpp, wifi_manager.cpp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]
2026-09-13 fix(ntp): phase A — RFC-honest LI, PPS ref stamp, tighter holdover dispersion
    Holdover no longer reuses LI=1 (leap-second bits); advertise LI=0 and raise
    root dispersion instead. Reference Timestamp uses the last PPS-aligned UTC
    second. Holdover quality uses a higher crystal floor, PHI minimum growth,
    entry uncertainty, and an early Unsynced cap when quality is too poor.
    [config.h, gps_service.cpp, gps_service.h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]
2026-09-13 chore(dist): add Phase A ESP32-C3 firmware zip for phone download
    Ship merged image and zip under dist/ so mobile GitHub can download
    without relying on agent artifact UI for .bin files.
2026-09-13 fix(wifi): preserve NVS credentials across OTA; SoftAP reconnect UX
    CRC mismatch no longer clears WiFi SSID/password (was forcing SoftAP after
    firmware updates). Boot keeps retrying saved STA instead of opening SoftAP
    when beginConnect is deferred. Setup page shows saved SSID with one-tap
    reconnect. Dist README documents app-only flash without full erase.
    [main.cpp]
2026-09-13 feat(ui): Scheme A home — large time, SSID, status corner chips
    Home OLED shows hierarchy: top sat/clock + RSSI/AP chips, centered
    size-2 local time, WiFi SSID line, IP with SYNC/WAIT. Residual and
    anomaly policy no longer clutter the primary view.
    [display_ui.cpp]
2026-09-13 fix(wifi): stop reason=8 false-fail from killing a live STA
    ASSOC_LEAVE (8) after disconnect()+begin was treated as join failure while
    GOT_IP still arrived. Auto-reconnect then disconnect()ed the good link on
    the next backoff and eventually opened SoftAP. Ignore local leave while
    joining, heal FSM when STA+IP already up, and never re-begin over a live
    association.
    [config.h, main.cpp, wifi_manager.cpp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]
2026-09-13 feat(security): B2 SoftAP pass from MAC + web write auth
    Default SoftAP password is NTP-<MAC low 16-bit hex>; serial prints MAC
    and pass at boot. POST /save requires JSON auth (NVS appw/webpw
    overrides); / /status /metrics stay open. OLED Web Setup shows pass.
2026-09-13 docs(b): intranet deploy checklist + 60s NTP UART summary
    Close out Phase B acceptance: README 内网部署 section, menu items for
    NTP ACL/Stats, and periodic [ntp] line on UART0 (NTP_STATUS_LOG_MS).
2026-09-13 docs: cancel Phase C (NTS/HTTPS/PTP/TCXO out of scope)
    Product scope stays at Phase A+B intranet Stratum-1; rack-grade
    features are not worth pursuing on ESP32-C3 + WiFi.
2026-09-13 fix(clock): multi-span ppm, esp_timer holdover, stricter acquire
    Estimate freq from the last 8 PPS intervals (then EMA) instead of a
    single 1s sample. Time holdover age with esp_timer to match the local
    scale. Bootstrap an anchor only after PPS looks stable.
    [config.h, local_clock.h]
2026-09-13 feat(clock): optional die-temp ppm trim (default Off)
    First-order Δppm = k·ΔT from the C3 TSENS vs the temperature at the
    last PPS frequency sample. NVS tcmp/tcpc, OLED Temp Comp, Web /setup.
    Correction clamped to ±20 ppm. Off leaves the previous servo unchanged.
    [config.h, display_ui.cpp, gps_service.cpp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]
2026-09-13 fix(web): restore /setup buttons after broken JS
    reconnectSaved() fetch() options were missing a closing paren, so the
    whole setup script failed to parse and every onclick was a no-op.
    Also show the default write password on the Auth card.
2026-09-13 fix(web): login page + session cookie; drop in-page write password
    HTTP Basic was easy to skip (captive portal / cached 200). /setup and
    SoftAP / now serve a login form first; settings HTML only after a
    cookie session. Remove SoftAP/Web password fields from the settings page.
    STA / remains the open status view.
    [display_ui.cpp]
2026-09-13 fix(web): close setup bypasses; login-only /cfg
    Keep / as read-only status. Drop HTTP Basic and JSON auth so
    browsers cannot skip the login page. Serve settings only at /cfg
    after a session cookie; /setup is login. Stop leaking the default
    password on /status. Settings page has no write-password field.
    [display_ui.cpp]
2026-09-13 docs(tools): Termux GPS vs Aliyun NTP compare script
    Self-contained stdlib script for Android Termux: query device
    UDP/123 and ntp.aliyun.com, pull /status, write CSV, print stats.
2026-09-13 fix(wifi): encoder scan works in SoftAP and during reconnect
    AP-only SoftAP has no STA iface so scanNetworks failed; raise to
    AP_STA first. Encoder scan aborts an in-progress join instead of
    returning busy/failed. Stay on the list page, treat empty as retry.
    [display_ui.cpp, main.cpp, wifi_manager.cpp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]
2026-09-13 fix(ui): detent filter so encoder clicks move one item
    KY-040 emits ~4 quadrature edges per notch; task-ui consumed each
    edge every 10 ms. Accumulate to a detent, drop idle remainder, and
    pace UI ticks so a light turn no longer jumps several rows.
    [config.h, encoder.cpp]
2026-09-14 dist: refresh phone-flash images (encoder filter)
    App @ 0x10000 plus merged 0x0 and zip for the current branch tip.
2026-09-14 fix(wifi): keep OLED scan list when STA is already up
    Channel-hop scan posts transient DISC and status texts that left
    the list page. Ignore those while scanning, harvest every AP
    (including hidden / non-ASCII), and stop /scan from immediately
    wiping a fresh result set.
    [display_ui.cpp, main.cpp, wifi_manager.cpp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]
2026-09-14 fix(wifi): deliver scan results to OLED before the next scan
    SCAN_DONE was followed by another scanNetworks(), which scanDelete()s
    the AP list before task-net harvested it. Harvest first, reuse pending
    results, never abort a live STA for encoder scan, and push the list
    whenever the OLED asked for one.
    [display_ui.cpp, main.cpp, wifi_manager.cpp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]
2026-09-14 fix(wifi): defer OLED scan until STA is up
    Encoder WiFi Scan was sending ScanFailed at request time while STA was
    still joining, so the screen showed failure before serial SCAN_DONE.
    Keep Scanning..., do not abortJoin, start the radio scan after GOT_IP,
    and ignore stale fail messages with a generation token.
    [config.h, display_ui.cpp, main.cpp]
2026-09-14 fix(ui): remove OLED WiFi scan and password entry
    Encoder scan never delivered a reliable AP list. Drop the menu item and
    the scan/password pages. WiFi join is Web Setup only (/scan + /save).
    task-net still harvests SCAN_DONE for the web portal.
    [config.h, display_ui.cpp, main.cpp]
2026-09-14 dist: refresh phone-flash images (no OLED WiFi scan)
    App @ 0x10000 plus merged 0x0 and zip after removing encoder scan.
2026-09-14 Revert "fix(ui): remove OLED WiFi scan and password entry"
    This reverts commit debf98bb92715379729c15bed2506db122735554.
    [config.h, display_ui.cpp, main.cpp]
2026-09-14 dist: refresh phone-flash images (OLED WiFi scan restored)
    App @ 0x10000 plus merged 0x0 and zip after restoring encoder scan.
2026-09-14 fix(ui): larger OLED config menu font
    Menu and scan list use 12x16 glyphs with invert highlight (4 rows).
    Timezone / Anomaly / ACL / Temp values are also size 2.
    [display_ui.cpp]
2026-09-14 fix(ui): OLED menu 18x24 and cache-bust firmware name
    Size-3 menu (3 rows, invert). Boot splash shows NTP UI2 so a stale
    cached firmware.bin is obvious. Also publish dist/fw-ui2.bin.
    [config.h, display_ui.cpp]
2026-09-14 fix(ui): menu 12x16 with extra row gap
    One step larger than the original 6x8, 3 rows, 6px between invert bars.
    Publish dist/fw-m2.bin so the previous fw-ui2.bin URL is not reused.
    [config.h, display_ui.cpp]
2026-09-14 fix(ui): OLED menu 4 rows at 12x16
    Same size-2 glyphs as M2, four items per screen (16px pitch).
    Publish dist/fw-m4.bin to avoid cached fw-m2.bin.
    [config.h]
2026-09-14 fix(ui): smaller menu font with 4 spaced rows
    6x8 glyphs, 4 rows, 10px invert bar and 6px gap so lines do not touch.
    Publish dist/fw-s4.bin to avoid cached fw-m4.bin.
    [config.h, display_ui.cpp]
2026-09-14 fix(ui): FreeSansBold 9pt menu with 4 spaced rows
    Vector-ish GFX font for the OLED menu and WiFi list. Same 4-row
    layout with a 3px gap. Publish dist/fw-vf.bin.
    [config.h, display_ui.cpp]
2026-09-14 fix(ui): use regular FreeSans 9pt on the OLED menu
    Drop FreeSansBold so strokes match the requested weight.
    Publish dist/fw-vr.bin to avoid the cached bold image.
    [config.h, display_ui.cpp]
2026-09-14 fix(ui): use FreeSans on all OLED screens
    Menu stays 9pt regular. Other pages use the same family: 9pt where
    the old size-1 bitmap was, 12pt where size-2 was (clock, values).
    Publish dist/fw-u9.bin.
    [config.h, display_ui.cpp]
2026-09-14 fix(ui): keep FreeSans 9pt on the menu only
    Other pages were packed because 9pt/12pt replaced 6x8. Restore the
    original size-1/size-2 layouts. Publish dist/fw-r1.bin.
    [config.h, display_ui.cpp]
2026-09-14 fix(ui): try FreeSerif 9pt on menu and large values
    Times-like serif on the menu, WiFi list, home clock, and setting
    values. Dense pages stay 6x8 so they do not pack. Publish fw-fs.bin.
    [config.h, display_ui.cpp]
2026-09-14 fix(ui): try FreeMono 9pt on menu and large values
    Monospace instead of FreeSerif. Dense pages stay 6x8.
    Publish dist/fw-fm.bin.
    [config.h, display_ui.cpp]
2026-09-14 fix(ui): show full OK IP, bigger clock, cluster WiFi icon
    Toast "OK <ip>" no longer truncates: 9pt OK plus 6x8 address.
    Home clock uses FreeMono Bold 12pt. WiFi glyph sits next to RSSI.
    [config.h, display_ui.cpp]
2026-09-14 docs: record 2026-09-14 Termux NTP compare
    Formal write-up of the 10-minute GPS vs Aliyun run, including
    the ACQ→LCK prefix and the archived CSV.
    [cmp_20260914_102829.csv]
2026-09-14 docs: evaluate LocalClock against two 10-min NTP compares
    Synthesize the 2026-09-11 PC run and 2026-09-14 Termux run with
    the 09-13 servo tightening. Mark the 10-min Aliyun regression done.
2026-09-14 fix(ui): seed static IP editor from live STA address
    When already connected to WiFi, open Set Static IP with the current
    LAN IP instead of a stale NVS value or SoftAP 192.168.4.1; also prefer
    the live gateway on the same /24 when saving.
    [display_ui.cpp]
2026-09-14 fix(wifi): skip reconnect when static IP already active
    [main.cpp]
2026-09-14 fix(ui): split long toasts into two centered 9pt lines
    [display_ui.cpp]
2026-09-15 fix(wifi): never give up reconnect; softap is manual only
    [config.h, wifi_manager.cpp]
2026-09-15 feat(ui): blank oled after idle, wake on encoder
2026-09-15 feat(sys): factory reset via 3s switch hold at power-on
    [config.h, display_ui.cpp, main.cpp]
2026-09-15 fix(sys): latch factory reset to once per power cycle
    [main.cpp]
